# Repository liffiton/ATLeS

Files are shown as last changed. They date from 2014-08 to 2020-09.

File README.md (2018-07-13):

# ATLeS: Automated Tracking and Learning System

The goal of the ATLeS project is to create an inexpensive, open-source system for automated, high-throughput, realtime observation and conditioning experiments.  Zebrafish, *danio rerio*, are the target organism for the initial design.

ATLeS consists of one or more ATLeS boxes, each of which can run an automated experiment on a single organism at a time, and a separate server that provides a combined interface for managing and controlling all of the boxes and their experiments in one place.
Each box uses an inexpensive [Raspberry Pi](https://www.raspberrypi.org/) as its "brain," an infrared-sensitive camera as its "eyes," and inexpensive materials for the structure.
A central server can connect to boxes over a network (ethernet or wifi) to control and manage them via a web interface.
The server software is written in Python, and it runs under Linux, OS X, or Windows.

Please visit the main [ATLeS website](https://liffiton.github.io/ATLeS) or look in the ``docs`` folder for more details and documentation.

## Authors

ATLeS was created by [Mark Liffiton](https://www.iwu.edu/~mliffito/) and [Brad Sheese](https://sites.google.com/view/bradsheese-researchandteaching/) at [Illinois Wesleyan University](https://www.iwu.edu/).

## Open-Source Licenses

Each part of the ATLeS project is licensed under one of two open-source licenses, depending on what type of material it is.  See [``docs/licenses.md``](docs/licenses.md) for details.

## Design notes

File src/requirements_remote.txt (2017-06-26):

numpy
plumbum
rpyc!=3.4
zeroconf
wiringpi

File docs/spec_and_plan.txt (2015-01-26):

FishyCam
========

Overview
--------

The end goal is to make a Skinner box for zebrafish.  The box will sense the fish's position and give the fish visual feedback based on its position and the history thereof.

Tanks are roughly 30cm x 15cm x 5cm (just guesses).  Position sensing will be on the x-y (30cm and 15cm) axes.  Feedback will be presented on one side of the tank in the same plane.

Input
-----

Spec:
 * Resolution of 100 positions across (longest dimension) is fine.  10x10 would be workable.
 * Realtime sensing and feedback
 * Ideally: automatic detection of position and orientation of tank within frame.
   * For consistent, scaled coordinates across experiments

Ideas:
 * Camera
   + Simple hardware -- cheap, easy to put together
   - Issues with glare, filtering, etc.
 * IR Camera (rpi)
   + Simple hardware
   + IR sensitivity / filtering (http://publiclab.org/wiki/near-infrared-camera)
   * Note: RPI Python OpenCV V4L2 stuff: http://www.raspberrypi.org/forums/viewtopic.php?f=43&t=65026&start=25
 * Photosensors
   + More robust (?)
   - More complex -- have to custom build it

Automatic position/orientation detection:
 * Apply markers to 4 corners of tank (at bottom and at water line)
   * Differentiate by color?  (possibly easiest)
   * Use a unique pattern?
 * Detect prominent lines in tank and find 4 lines w/ most appropriate ratios/slopes to be the tank
   * http://stackoverflow.com/a/17265438

Output
------

Ideas:
 * Monitor
   + Most flexible -- any image/animation can be displayed
   + Simple hardware -- no construction required
   - Cost (potentially)
   - Issues with glare, filtering, given the camera is facing the display
 * Matrix of LEDs
   + Potentially easier to filter out
   + Inexpensive
   - Requires custom building
   - Low resolution

Plan
----

Webcam for sensing, monitor for feedback.

Software
--------

Interface needs:
  * Setup
    * ???
  * Monitor
    * Time experiment started, time running
    * View experiment parameters?
    * View current data?  (Form?)
    * Current video feed
      * Ideally live video, but a current still should be alright
  * Control
    * Stop experiment
  * Download
    * Data from previous experiment
    * Data from all past experiments
    * Data from selected experiment(s)
    * ?Form?

Interface options:
  * Web-based or GUI app
    * Web-based most accessible
    * GUI app runs where?  Via SSH?  Or physically at the machine itself?
  * Per-box or single centralized
    * Per-box is actually simpler to setup, maintain
    * Single centralized could be more usable

Data:
  * ???Form???
  * Centralized database?
    * Would be useful, but adds a lot of complexity

Feedback:
  * Animations?
    * If so, run in a separate thread
    * Thread 1: Track fish and make feedback decisions
    * Queue for messages, thr1->thr2
    * Thread 2: Animation, responding to messages in queue

API flow:
  frame = cv2.get...
  proc.proc(frame)
  tracker.update(proc.centroids)
  track.store(tracker.position)
  feedback.update(track)

General coding:
  * Use logging package, log any uncaught exceptions (crashes):
      http://blog.tplus1.com/blog/2012/08/05/python-log-uncaught-exceptions-with-sys-excepthook/
  * Animation:
     * Use pyprocessing for animation?
       http://code.google.com/p/pyprocessing/
     * Or use pyglet directly?
     * Pyprocessing will likely be easier for others to use for making new 'plugins'.
  * Use multiprocessing.{Process|Queue} for 'threading' and communication
  * Setup a 'plugin' architecture, with a directory for 'feedback' plugins and a directory for 'trigger' plugins?

**OR**
Build on pre-existing software:
  https://en.wikipedia.org/wiki/Comparison_of_behavioral_experiment_software
  * Python:
    * OpenSesame looks feature-rich
      * Uses PsychoPy or Expyriment for backends
    * PsychoPy also has a graphical experiment builder
    * Expyriment is code only, and it might not offer much we need...

Scripting options:
  * Let users create experiments in raw Python
  * Use a graphical editor like OpenSesame or PsychoPy (or one of those directly)
  * Blockly!  Can export to Python.  Can likely create custom blocks for various functions/variables of interest...!

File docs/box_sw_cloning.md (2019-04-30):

---
title: Box Software Cloning
---

# Box Software Cloning

These instructions are for developers who wish to clone an existing ATLeS box
Raspberry Pi installation to create a new base OS image for installing on new
boxes.

## Making a New Image

To save a disk image of a working/configured Raspberry Pi SD card:

[TODO: Could simplify to `dd` plus an automated script using loopback, https://github.com/Drewsif/PiShrink, and some of the steps below.]

1. Put card into card reader in a Linux machine.

2. (Optional) Use the `dist/prep_image.sh` script to remove unneeded files from
   the card before cloning.

3. Unmount the partitions if auto-mounted (Ubuntu auto-mounts them)

       $ sudo umount /dev/[device of auto-mounted partition[s]]

4. (Optional) Use `gparted` to shrink the root partition on the card to just
   the used space plus a small buffer.  (E.g., with 2.20GiB used, `resize2fs`
   wouldn't let me make it 2500MiB, but 3000MiB was okay.)

5. (Optional) Zero unused blocks in the root partition so the disk image can be
   compressed more.  Requires the `zerofree` utility.  If `/dev/sdc2` is the
   root partition:

       $ sudo zerofree -v /dev/sdc2

6. Determine the number of blocks now occupied.
   (Adapted from: [http://raspberrypi.stackexchange.com/a/8314](http://raspberrypi.stackexchange.com/a/8314))

       $ sudo fdisk -l /dev/[device of entire card (e.g., sdd)]
   
   Prints the partition table.

   Record 'End' of the final partition and the sector size.

7. Use `dd` to create the image using the size from the previous step.
    
       $ sudo dd bs=[sector size] count=[end of final partition + 1] if=/dev/[device of entire card] of=atles_rpi_`date +%Y%m%d`.img status=progress

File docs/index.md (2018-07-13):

---
title: Automated Tracking and Learning System
---

# ATLeS

The goal of the ATLeS project is to create an inexpensive, open-source system for automated, high-throughput, realtime observation and conditioning experiments.  Zebrafish, *danio rerio*, are the target organism for the initial design.

{:.center}
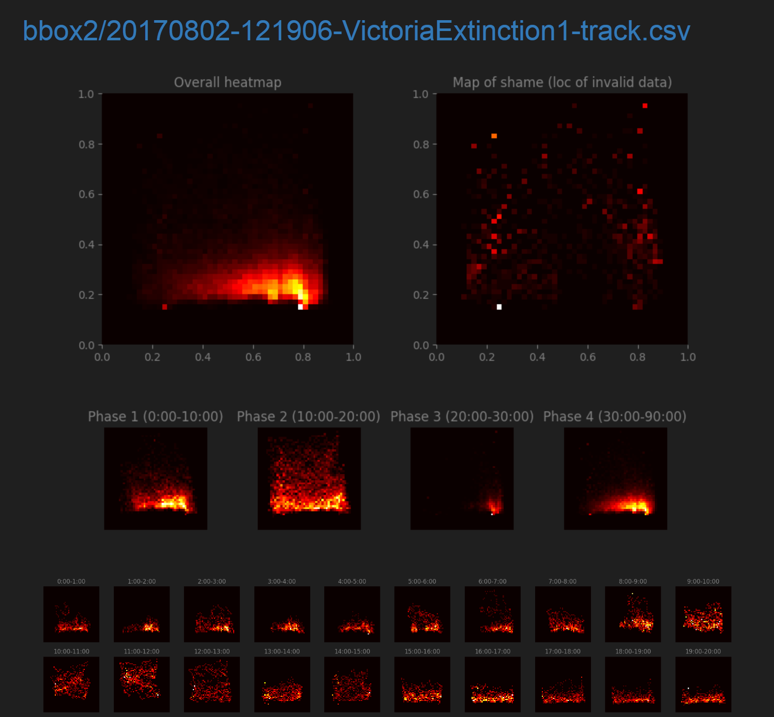
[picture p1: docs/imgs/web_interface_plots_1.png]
ATLeS Plots 1

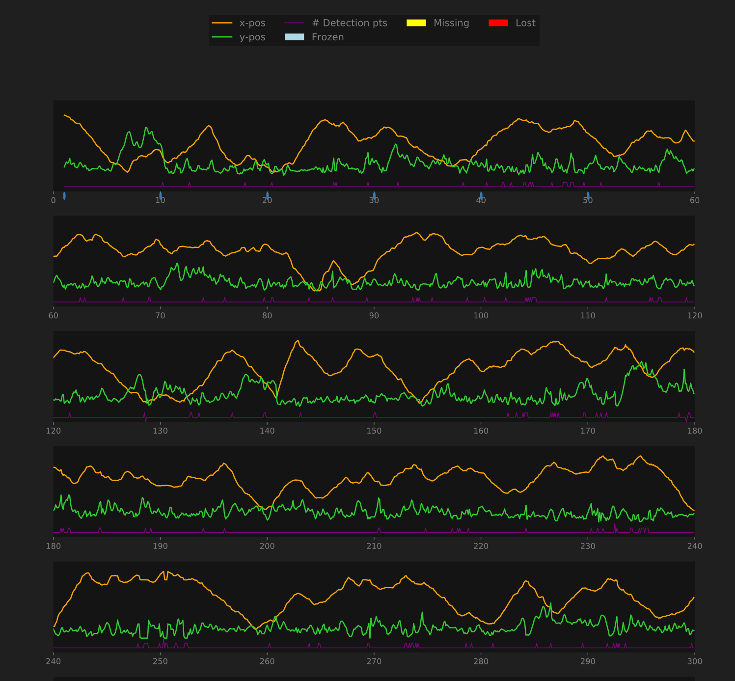
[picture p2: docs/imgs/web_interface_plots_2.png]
ATLeS Plots 2


ATLeS consists of one or more ATLeS boxes, each of which can run an automated experiment on a single organism at a time, and a separate server that provides a combined interface for managing and controlling all of the boxes and their experiments in one place.
Each box uses an inexpensive [Raspberry Pi](https://www.raspberrypi.org/) as its "brain," an infrared-sensitive camera as its "eyes," and inexpensive materials for the structure.
A central server can connect to boxes over a network (ethernet or wifi) to control and manage them via a web interface.
The server software is written in Python, and it runs under Linux, OS X, or Windows.

ATLeS was created by [Mark Liffiton](https://www.iwu.edu/~mliffito/) and [Brad Sheese](https://sites.google.com/view/bradsheese-researchandteaching/) at [Illinois Wesleyan University](https://www.iwu.edu/).

# Make Your Own

All source files, including code and complete designs for physical parts, are available in the [ATLeS Github repository](https://www.github.com/liffiton/ATLeS).

Building a single ATLeS box costs roughly $100 and requires some assembly and wiring.  The enclosure is designed to be laser cut from hardboard or similar flat, rigid materials.  Using the provided design files, you can either laser-cut the pieces yourself or order them from an online laser-cutting service.

{:.center}
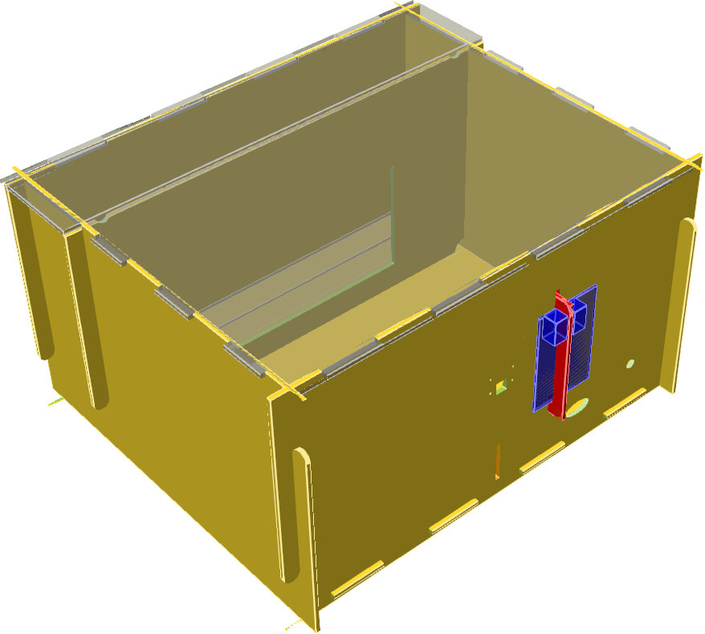
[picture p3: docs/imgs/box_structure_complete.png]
Complete ATLeS Enclosure


The following pages walk you through the assembly and software installation:

 * [Building an ATLeS Box Enclosure](building)
 * [System Integration & Setup](setup)

# Use It

After the boxes are assembled and the software is installed, run ``src/atles_web.py`` and point a browser to ``http://[hostname]:8080/``.  As you turn on boxes, they should become visible in the main web interface.

{:.center}
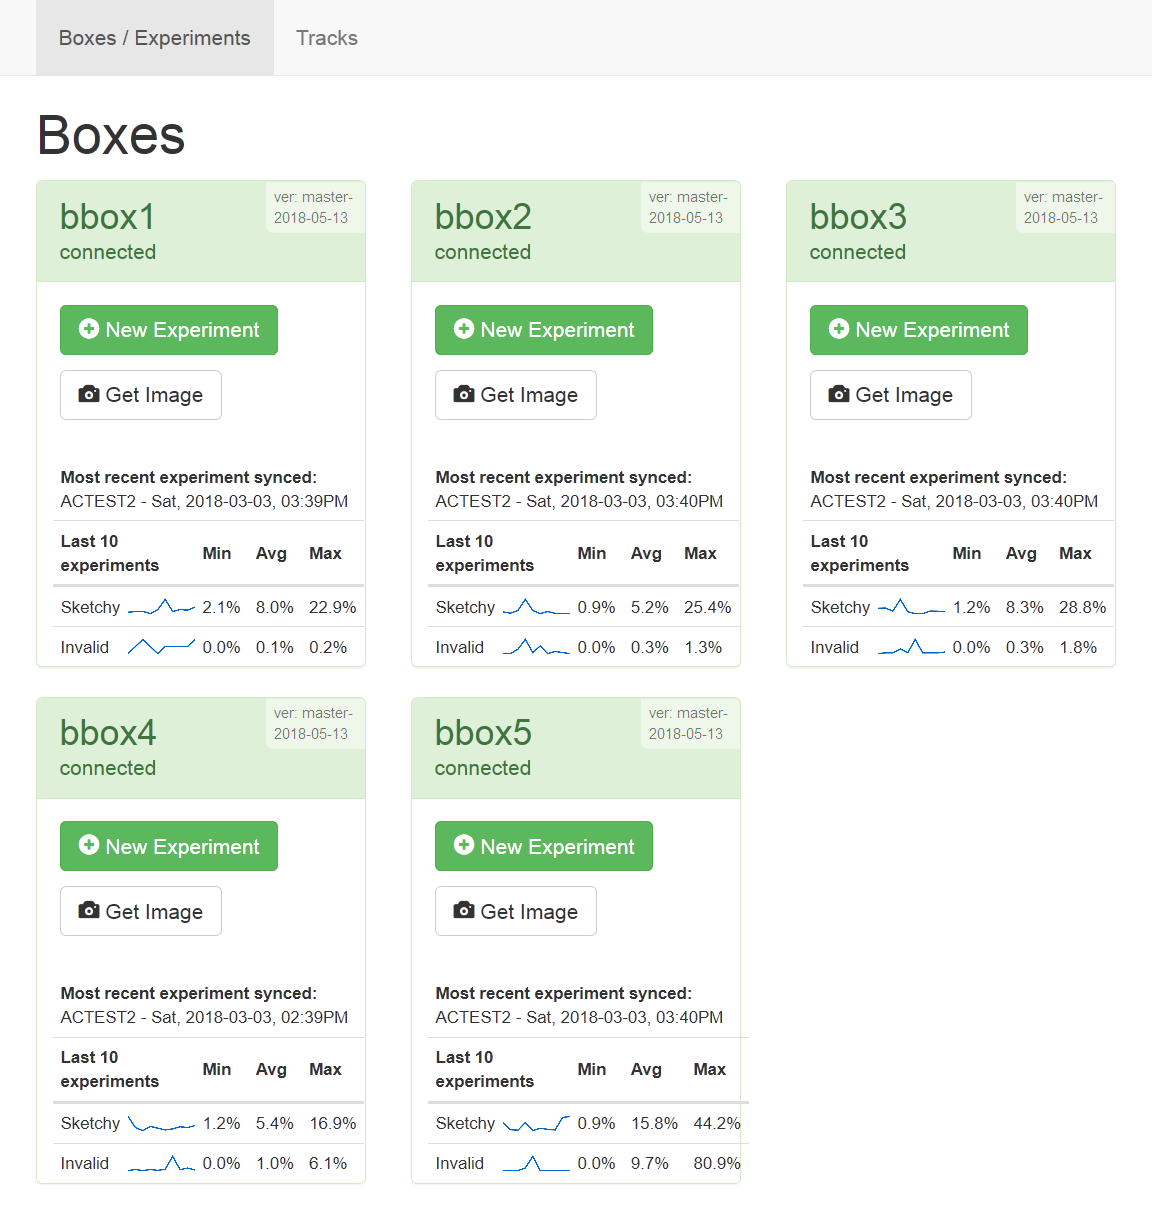
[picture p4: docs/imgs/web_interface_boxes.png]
Main ATLeS web interface


The web interface displays the status of every connected box, provides an interface for launching and monitoring experiments, and includes a full set of analysis and visualization tools for collected data.

The following page provides more details:

 * [Using ATLeS](usage)

# Adapt It

Because the entire system is open-source, from the code to the physical design, you can modify and adapt the system to suit your needs.  Modify the enclosure to accommodate a different style of tank.  Tweak the software to perform a different analysis.  Or just take a component out to use in your own system.  See [Licenses](licenses) for details.

The following pages provide information for anyone interested in modifying or working on the software:

 * [(Manual) box software installation](box_sw_manual_install)
 * [Box software image cloning](box_sw_cloning)
 * [Box software usage notes](box_sw_notes)

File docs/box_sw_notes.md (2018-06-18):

---
title: Box Software Usage Notes
---

# Notes on Running `atles_box.py`

## Framerate

The capture framerate is sensitive to many things.

First, displaying the captured frames using highgui takes a huge amount of CPU time, making it infeasible (i.e., maxing out CPU) above 10fps.  Without displaying the images, however, CPU usage doesn't hit 100% until about 50fps.

Secondly, the capture size obviously makes a difference.  There is currently some bug in the interaction between OpenCV and V4L that makes it impossible to change the capture size after the stream is opened in OpenCV (at its default 640x480 size).  See [opencv_notes](opencv_notes) for directions for how to modify and compile OpenCV to fix this bug.  The fix allows us to set the video capture size smaller for better performance.  160x120 seems nice and fast, and we have lots of flexibility now.

Also, it is important to note that terminal output, displayed on the rpi's X server, uses a large amount of the CPU as well.  Simply switching to a different tab while FPS output is enabled in camtest.py drops the CPU usage significantly.  Keep this in mind particularly during testing, where debugging output may significantly harm performance.

## Exposure and white balance

Auto white balance can be disabled with:

    $ v4l2-ctl --set-ctrl=white_balance_auto_preset=1
    $ v4l2-ctl --set-ctrl=white_balance_auto_preset=0

It does seem to need to be set to 1 then back to 0 to work, at least sometimes.  Without that, AWB is somehow enabled between(?) runs, and just setting the preset to 0 at the start of the next does not work.  The set to 1 then back does work, it appears.

Exposure can be adjusted with:

    $ v4l2-ctl --set-ctrl=auto_exposure=1
    $ v4l2-ctl --set-ctrl=exposure_time_absolute=10000
    $ v4l2-ctl -p 1

"auto_exposure=1" disables auto exposure (don't ask me...).
"exposure_time_absolute" is given in multiples of 0.1ms.  It needs to be adjusted along with the frame rate (-p) so that they match.  A higher frame rate will clip the exposure to make that frame rate possible.

## Display

In X, pygame will make a fullscreen view, but it won't (as far as I've found so far) scale the image.  So if I request 640x480, I get a 640x480 surface in the middle of my monitor.

Running from the terminal, however, does work.  I don't know what interface SDL is using, exactly, but it seems alright.  It seems to only work *once*, though.  Running the program a second time results in a blank screen.  I may be using Pygame incorrectly...

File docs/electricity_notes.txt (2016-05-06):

May 6, 2016

Measuring resistance through H2O between two pieces of Al foil:  multimeter says >2MOhm.

Current:
  * Measured by DMM with voltage set on power supply
  * With Al foil on **inside** of plastic baffles, right at baffles:
    * 32V -> 75mA
    * 20V -> 47mA
    * 15V -> 35mA
    * 10V -> 22mA
    * 5V  -> 10mA
    * 2V  ->  3mA
  * With Al foil on **outside** of plastic baffles (only conductance via thin gaps at edges):
    * 20v -> 16mA
  * Baffles **block a lot**

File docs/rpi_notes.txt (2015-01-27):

FishyCam on the Raspberry Pi
============================

Package dependencies
--------------------

python-smbus

**TODO (others?)**

Runtime dependencies
--------------------

In order to use the camera via v4l, one must first load a module:

  sudo modprobe bcm2835-v4l2

Then, OpenCV's v4l2 support works reasonably well (though see Framerate below).

Using the i2c interface also requires a module:

  sudo modprobe i2c-bcm2708
  sudo modprobe i2c-dev

Alternatively, you can add the modules to /etc/modules, one per line:

   bcm2835-v4l2
   i2c-bcm2708
   i2c-dev

Framerate
---------

The capture framerate is sensitive to many things.

First, displaying the captured frames using highgui takes a huge amount of CPU time, making it infeasible (i.e., maxing out CPU) above 10fps.  Without displaying the images, however, CPU usage doesn't hit 100% until about 50fps.

Secondly, the capture size obviously makes a difference.  However, there is currently some bug in the interaction between OpenCV and V4L that makes it impossible to change the capture size after the stream is opened in OpenCV (at its default 640x480 size).  However, a user on the rpi forums has posted a fix to OpenCV:
  http://www.raspberrypi.org/forums/viewtopic.php?f=43&t=62364&start=322

It requires modifying and recompiling OpenCV.  I have adopted his/her modifications, allowing me to set the video capture size smaller for better performance.  160x120 seems nice and fast, but we have lots of flexibility now.

Secondly, then, it is important to note that terminal output, displayed on the rpi's X server, uses a large amount of the CPU as well.  Simply switching to a different tab while FPS output is enabled in camtest.py drops the CPU usage significantly.  Keep this in mind particularly during testing, where debugging output may significantly harm performance.

Exposure and white balance
--------------------------

Auto white balance can be disabled with:
 v4l2-ctl --set-ctrl=white_balance_auto_preset=1
 v4l2-ctl --set-ctrl=white_balance_auto_preset=0

It does seem to need to be set to 1 then back to 0 to work, at least sometimes.  Without that, AWB is somehow enabled between(?) runs, and just setting the preset to 0 at the start of the next does not work.  The set to 1 then back does work, it appears.

Exposure can be adjusted with:
 v4l2-ctl --set-ctrl=auto_exposure=1
 v4l2-ctl --set-ctrl=exposure_time_absolute=10000
 v4l2-ctl -p 1

"auto_exposure=1" disables auto exposure (don't ask me...).
"exposure_time_absolute" is given in multiples of 0.1ms.  It needs to be adjusted along with the frame rate (-p) so that they match.  A higher frame rate will clip the exposure to make that frame rate possible.

Display
-------

In X, pygame will make a fullscreen view, but it won't (as far as I've found so far) scale the image.  So if I request 640x480, I get a 640x480 surface in the middle of my monitor.

Running from the terminal, however, does work.  I don't know what interface SDL is using, exactly, but it seems alright.  It seems to only work *once*, though.  Running the program a second time results in a blank screen.  I may be using Pygame incorrectly...

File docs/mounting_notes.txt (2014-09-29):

Mounting the Raspberry Pi and Camera
====================================

Requirements
------------

  * Camera must be held in correct orientation (i.e., right-side-up).
  * Camera must be facing fish tank.
  * Camera should be as close to a set distance from and orientation w.r.t. the fishtank as possible.
  * Raspberry Pi must be within flex-cable-range of camera.
  * SD card, USB, HDMI, and ethernet must all be accessible on RPi.
  * Monitor should be mounted in set position w.r.t. fishtank.
  * All should be splash-proof (for whatever direction splashes might come from).

Ideas
-----

Monitor:
  * VESA mount would accomodate most regular monitors, but:
    * Most regular monitors are larger than needed
    * There are two(?) VESA standards
    * Even w/in same monitor size, VESA mounts are likely not all in same position on monitor
  * Specific smaller monitor
    * E.g.: https://www.adafruit.com/products/1287 ($150ish)
    * Requires mounting monitor and control board

Construction:
  * Clear acrylic
    * Camera, Pi, monitor(?) mounted w/ simple bolts through mounting holes
      * Consider nylon screws/nuts, if you can find them.
      * For RPi, M2.5 or 4-40 screws should work fine.  4-40 plentiful at HD.
      * For camera, M2 screws work, and imperial size 2 (e.g. 2-56) might *just* fit...  Imperial size 1 is better, but...  not easy to find.
    * Holes in acrylic drilled *or* laser-cut
    * Simple, splash-proof from direction of tank
    * ? How to hold two pieces of acrylic (w/ some load) vertically in correct position?
      * Threaded rod?  Seems good.
      * Acrylic side pieces as well?  Then could be 100% laser-cut.
    * ? How to position fishtank?
      * Bottom piece of acrylic w/ laser-cut slots for tank "feet"?
      * Cut piece for holding outline of tank in place?

Existing enclosure designs
==========================
  * Enclosure for camera alone
    * https://github.com/luisibanez/ShapesFor3DPrinting/tree/master/OpenSCAD
      * Shown on https://www.thingiverse.com/thing:214466
  * Enclosure for Pi alone
    * http://www.thingiverse.com/thing:16104/
  * Full enclosure for Pi and Camera
    * http://www.thingiverse.com/thing:177816
    * http://www.thingiverse.com/thing:142608
    * http://www.thingiverse.com/thing:89745
    * Note remixes of above, as well
    * Cleaner, but not entirely needed...
    * But definitely better protection for electronics...

Questions
---------
  * Lighting?  Need sufficient for camera.  Does it need to be constant / standard for any experiments?

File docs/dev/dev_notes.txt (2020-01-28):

"Dev" RPi 3 B+: 10.2.6.36  [in Mark's office]
fishhead: 10.2.53.25

To run main web interface:
  sudo python src/atles_web.py --daemon

Fish tank measurements:
 - Height w/ feet:   16.0cm
 - Height w/o feet:  15.4cm
 - Width:             7.0cm
 - Length w/ lid:    34.8cm
 - Length w/o lid:   33.3cm
 - Diagonal (approx. screen size needed): 14.4" (36.7cm)

Electricity
-----------
May 6, 2016

Measuring resistance through H2O between two pieces of Al foil:  multimeter says >2MOhm.

Current:
  * Measured by DMM with voltage set on power supply
  * With Al foil on **inside** of plastic baffles, right at baffles:
    * 32V -> 75mA
    * 20V -> 47mA
    * 15V -> 35mA
    * 10V -> 22mA
    * 5V  -> 10mA
    * 2V  ->  3mA
  * With Al foil on **outside** of plastic baffles (only conductance via thin gaps at edges):
    * 20v -> 16mA
  * Baffles **block a lot**

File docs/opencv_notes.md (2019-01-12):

These notes are out of date and preserved just in case.  Follow the instructions in [box_sw_manual_install](box_sw_manual_install) instead.

Installing an Updated OpenCV on the Raspberry Pi
===============================================

The following instructions assume an updated Raspbian system.

Based on [OpenCV Linux Install][].

[To build/install on Cygwin, see [OpenCV Cygwin Install][].]

[OpenCV Linux Install]: http://docs.opencv.org/doc/tutorials/introduction/linux_install/linux_install.html
[OpenCV Cygwin Install]: http://hvrl.ics.keio.ac.jp/kimura/opencv/

Build dependencies
------------------

Packages that need to be installed in addition to the defaults.  [There may be
something missing here that isn't included in the default Raspbian install, but
this is what I had to add to my current setup.]

```
cmake
libgtk2.0-dev
python3-dev
libavcodec-dev
libavformat-dev
libswscale-dev
libpng-dev
libjasper-dev
libtiff-dev
```

To install these:

    $ sudo apt-get install cmake libgtk2.0-dev python3-dev libavcodec-dev libavformat-dev libswscale-dev libpng-dev libjasper-dev libtiff-dev

Download OpenCV
---------------

ATLeS currently works and has been tested with OpenCV 3.2.0.  You can download
this release from [OpenCV's Releases page](http://opencv.org/releases.html).
ATLeS will likely work with other versions, but compatibility is not guaranteed.

Build instructions
------------------

In the opencv-3.2.0 directory, run:

```sh
$ mkdir release
$ cd release
$ cmake -D CMAKE_BUILD_TYPE=RELEASE -D CMAKE_INSTALL_PREFIX=/usr/local -D BUILD_EXAMPLES=off -D BUILD_TESTS=off -D BUILD_PERF_TESTS=off ..
```

In the output of cmake, verify that "OpenCV modules">"To be built" lists
python, "GUI" has "YES" for GTK+, and the "Python" section lists correct paths
to binaries/libraries.  Tests, examples, and performance tests are not built to
save space.  It takes far too much space with those enabled (I ran out of space
with 1.1GB free to start).

    $ make

This step, building OpenCV with the above configuration, takes about 4 hours on
the RPi B+.

    $ sudo make install

The easiest way to check the installation now is to launch the python
interpreter and type `import cv2`.  If it does not report an error when
importing the module, the installation is probably complete.

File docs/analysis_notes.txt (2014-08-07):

From Brad's hand-written notes (Jul 2014)

Cachet et al. 2010
------------------

 * # of entries to top
 * Entries top/bottom ratio
 * Time spent in top (s)
 * Time spent top/bottom ratio
 * Average entry duration (time spent in top divided by the number of entries to top)
 * Distance traveled in top (m)
 * Distance traveled top/bottom ratio
 * Latency to enter the top (s)
 * # of erratic movements
 * Freezing bouts (frequency)
 * Freezing duration (s)
 * Distance traveled (m)
 * Velocity (m/s)
   [note for last two: 'claim these represent hyperactivity']

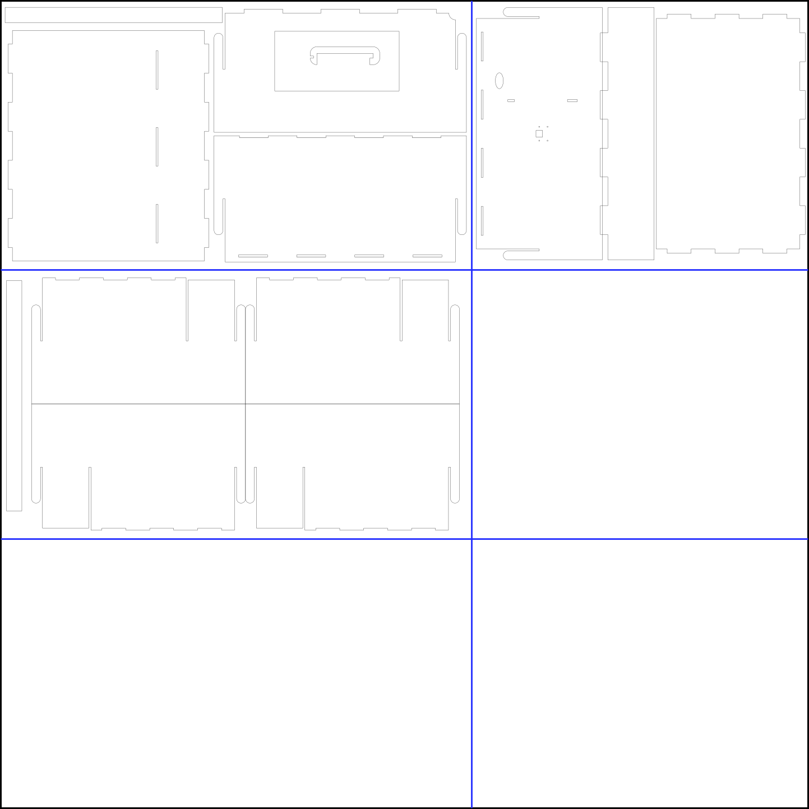
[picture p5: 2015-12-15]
designs/box/paneling.png

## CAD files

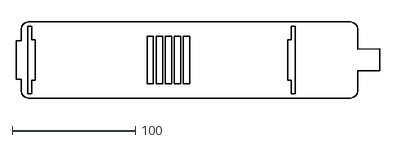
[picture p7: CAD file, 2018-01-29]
designs/dist/tank_lid_for_shock.dxf
294.6 x 61.7

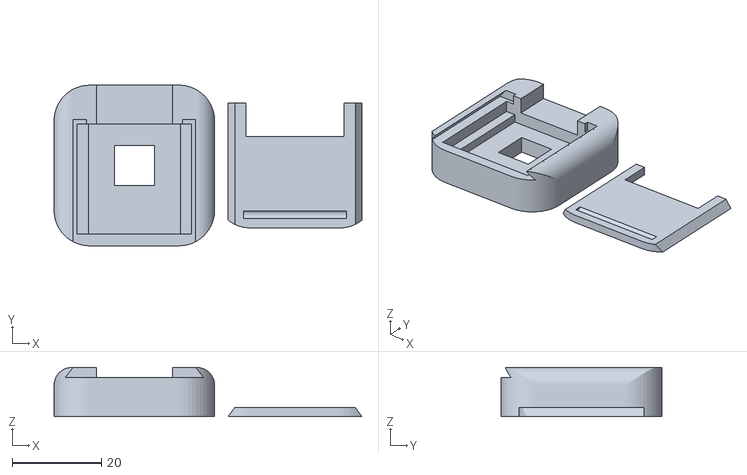
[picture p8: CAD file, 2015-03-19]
designs/piCameraEnclosure.stl
69.0 x 36.0 x 11.0

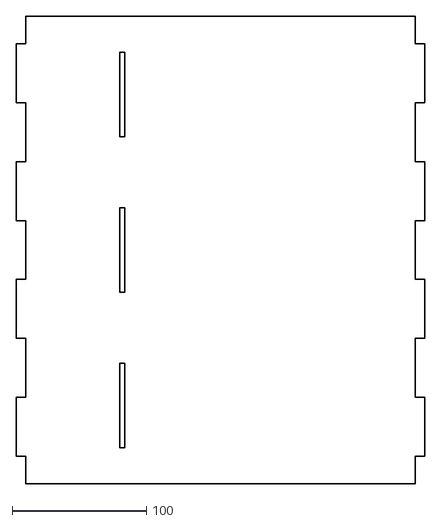
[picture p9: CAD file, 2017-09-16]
designs/dist/bottom.dxf
304.5 x 348.0

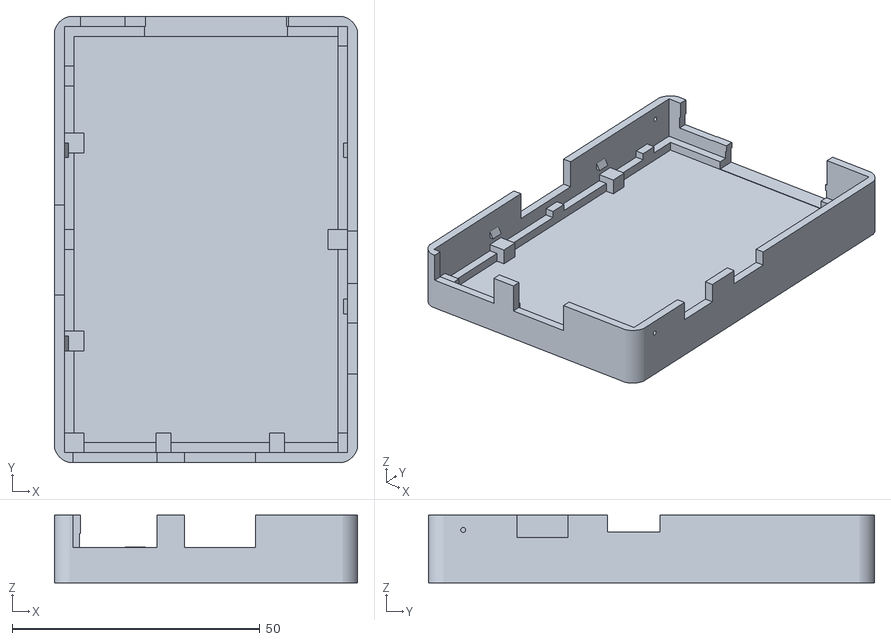
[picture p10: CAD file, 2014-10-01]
designs/RaspberryPi_v15_bottom.stl
61.2 x 90.0 x 13.7

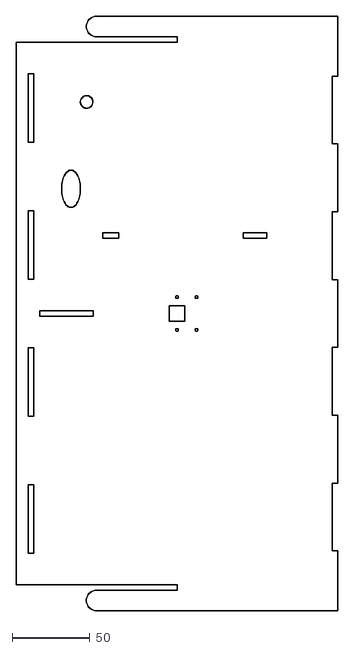
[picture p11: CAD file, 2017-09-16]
designs/dist/end2.dxf
206.0 x 381.5

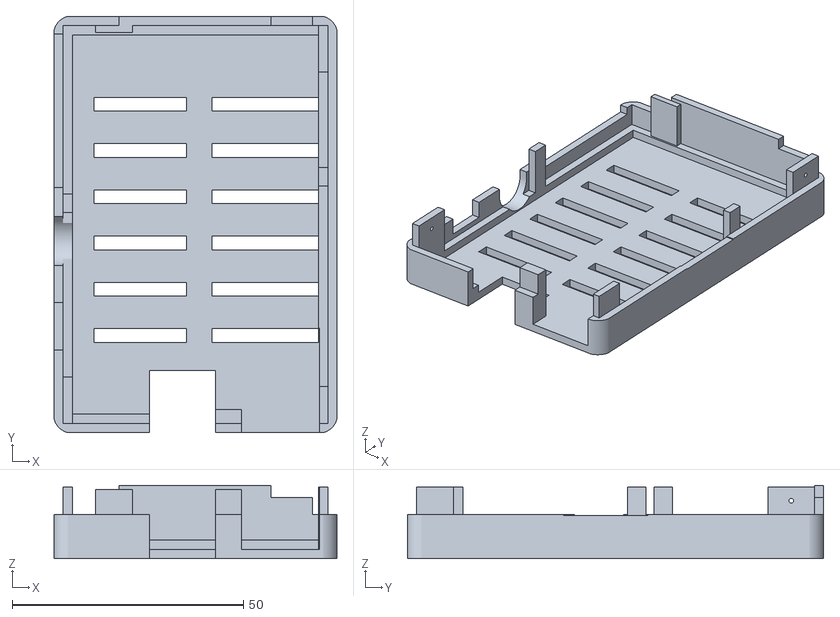
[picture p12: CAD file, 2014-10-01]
designs/RaspberryPi_v15_top.stl
61.2 x 90.0 x 15.8

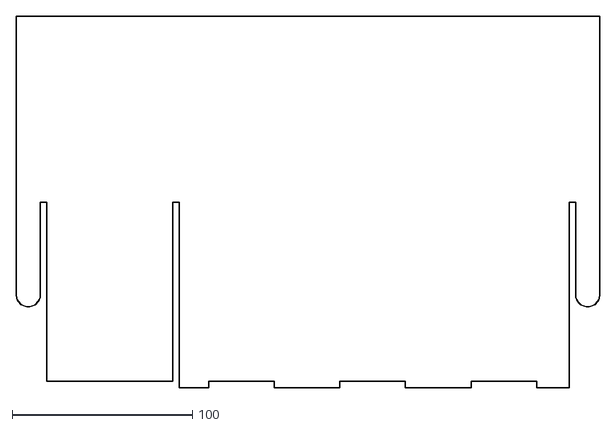
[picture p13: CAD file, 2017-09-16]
designs/dist/side1.dxf
323.5 x 206.0

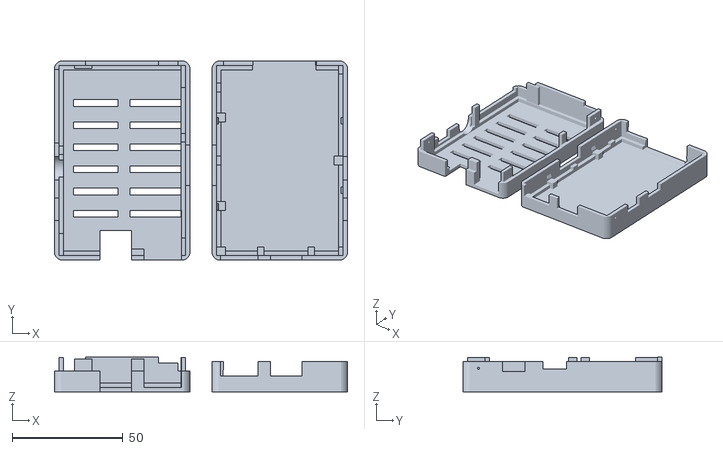
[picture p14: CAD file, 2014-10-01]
designs/RaspberryPi_v15.stl
132.4 x 90.0 x 15.8

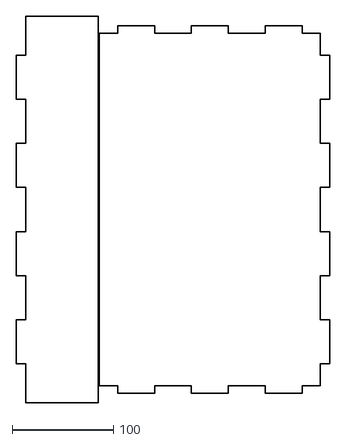
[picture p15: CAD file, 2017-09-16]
designs/dist/top.dxf
309.0 x 381.5

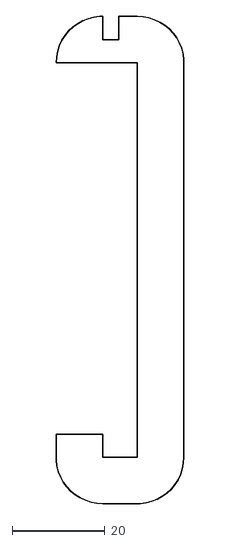
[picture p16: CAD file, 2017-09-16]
designs/dist/rpi_support.dxf
27.5 x 105.0

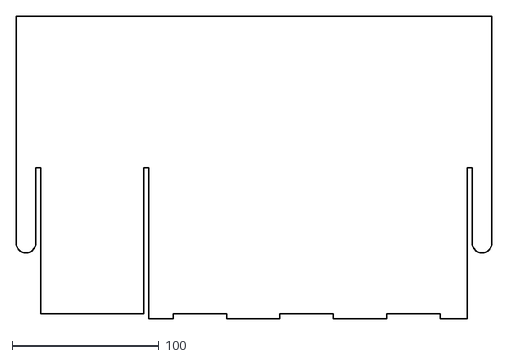
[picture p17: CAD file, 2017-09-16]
designs/dist/side2.dxf
323.5 x 206.0

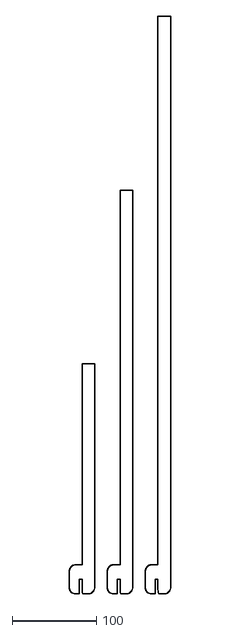
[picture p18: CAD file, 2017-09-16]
designs/dist/rear_support.dxf
120.0 x 684.5

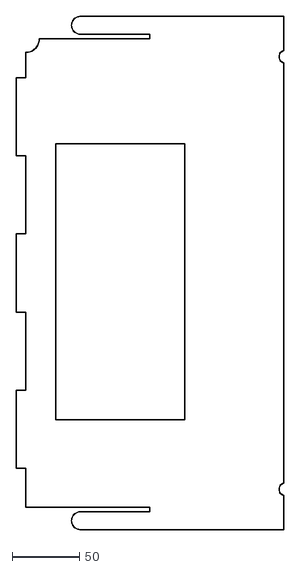
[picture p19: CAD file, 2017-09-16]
designs/dist/mask.dxf
198.5 x 381.5

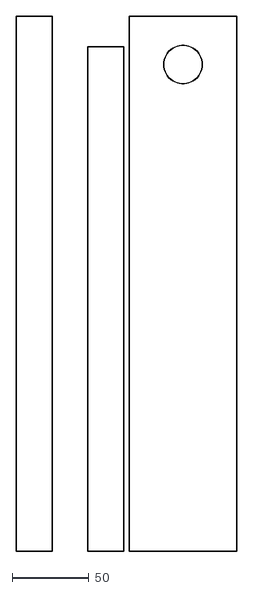
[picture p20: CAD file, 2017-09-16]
designs/dist/tank_support.dxf
143.5 x 348.0

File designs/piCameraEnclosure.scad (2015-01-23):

// Adapted from: https://github.com/luisibanez/ShapesFor3DPrinting/tree/master/OpenSCA

// For case
width  = 36;  // x
length = 36;  // y
height = 11;  // z

// For camera cover
flex_adapter_width = 22;   // measures 21mm, but w/ a nominal 22mm opening it was still too tight.
cover_width = 27;
cover_height = 2;

// For rounded corners
radius1 = 8;
radius2 = 4;

piCameraAdapter();
// Comment out translate to see
// back cover in place.
translate([width,4,-(height-cover_height)])
    piCameraBackCover();


/////////////////////////////////////////////////////////////////////////////////////
// Modules
//

module piCameraBackCoverBevel(length, clearance) {
    c = clearance;
    hh = cover_height / 2;
    hw = ( cover_width / 2 ) + c;
    he = hw + 1.5 + c;
    l = length / 2;
    polyhedron(
        points = [
            [ hw, -l-c, -hh-c ],
            [ hw,  l+c, -hh-c ], 
            [ hw,  l+c, hh ], 
            [ hw, -l-c, hh ],
            [ he, -l-c, -hh-c ],
            [ he,  l+c, -hh-c ] 
            ], 
        faces = [
            [ 5, 1, 0, 4],
            [ 4, 0, 3 ],
            [ 2, 1, 5 ],
            [ 5, 4, 3, 2],
            [ 0, 1, 2, 3],
        ]
    );
}

module piCameraBackCover(for_subtraction=false) {
    indent = ! for_subtraction;
    clearance = for_subtraction ? 0.25 : 0;
    c = 2*clearance;
    cov_l = length-8;
    difference() {
        translate([0,-5,height-cover_height/2])
        difference() {
            translate([0,1,0])
            union() {
                cube(size=[cover_width+c,cov_l+c,cover_height+c],center=true);
                piCameraBackCoverBevel(cov_l, clearance);
                mirror([1,0,0])
                    piCameraBackCoverBevel(cov_l, clearance);
            }
            translate([0,15,0])
                cube(size=[flex_adapter_width-c,15,100],center=true);
            if (indent)
                translate([0,8-length/2,cover_height/2+0.5])
                rotate([0,90,0])
                    cylinder(r=1, h=cover_width-4, center=true, $fn=20);
        }
        if (! for_subtraction) {
            cornerRounding();
        }
    }
}

module cableOpening() {
    w = 17;
    d = 12;
    h = 100;
    translate([-w/2,2+d/2,height-4+0.1])
        cube(size=[w,d,h]);
}

module lensOpening() {
    clearance = 0.5;
    c = 2 * clearance;
    w = 8+c;
    d = 8+c;
    h = 100;
    translate([-w/2,-d/2,-1])
        cube(size=[w,d,h]);
}

module boardOpening() {
    clearance = 0.3;
    c = 2 * clearance;
    w = 25+c;
    d = 24+c;
    h = 100;
    translate([-w/2,-d/2 - 3, height-5])
        cube(size=[w,d,h]);
}

module chipOpening() {
    clearance = 0.3;
    c = 2 * clearance;
    w = 20+c;
    d = 24+c;
    h = 100;
    translate([-w/2,-d/2 - 3, height-7])
        cube(size=[w,d,h]);
}

module cameraFrame() {
    translate([0,0,height/2])
        cube(size=[width,length,height], center=true);
}

module roundedCorner(r) {
    translate([-r, -r, 0])
    difference() {
        translate([0,0,-50])
            cube(size=[r+0.1,r+0.1,100]);
        cylinder(h=100, r=r, $fn=50, center=true);
    }
}

module cornerRounding() {
    // vertical corners
    translate([width/2,length/2,0])
        roundedCorner(radius1);
    translate([-width/2,length/2,0])
    rotate([0,0,90])
        roundedCorner(radius1);
    translate([-width/2,-length/2,0])
    rotate([0,0,180])
        roundedCorner(radius1);
    translate([width/2,-length/2,0])
    rotate([0,0,-90])
        roundedCorner(radius1);

    // top corners
    translate([-width/2,0,height])
    rotate([0,-90,0])
    rotate([90,0,0])
        roundedCorner(radius2);
    translate([width/2,0,height])
    rotate([90,0,0])
        roundedCorner(radius2);
}

module piCameraAdapter() {
    difference() {
        cameraFrame();
        boardOpening();
        chipOpening();
        cableOpening();
        lensOpening();
        cornerRounding();
        piCameraBackCover(for_subtraction=true);
    }
}

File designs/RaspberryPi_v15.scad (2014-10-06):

// Raspberry Pi Case
// Hans Harder 2012
//
// Warning: this is based on the Beta board dimensions...
//          so production models can be slightly different
//          for instance SD card holder height and USB socket dimensions
//
// Since all connectors stick out, case is split on HDMI height
// so the power and sdcard holder goes in first and then the pcb drops into place.
//
// v2: Adapted version after some suggestions from David...
//     removed feet, made both surface flat
// v3: Added fliptop option and smooth the corners of the box
// v4: Different levels of case split (make it 3d printable, thx David)
//     Looks strange but it fits...
//     Added frame mode (so no bottom and top deck)
//     Moved screw locations due to split and added some support structures
//     Unsure about 2nd screw location in combination with GPIO pins
// v5  relocated a lot of code in modules
//     SDslot location was not calculated correctly
// v6  Added pcb drawing
//     Added colors
//     Cut out better so there is no debris around
//     DRAwvars and options seperated, so it is easier to do 1 part
//     Make a low as possible case, let USB stick out
// v7  PCB options
//     Low level case optimisations
//     SD card location alterations
// v8  adapted pcb dimensions, board is really 56mm width
//     adapted support studs, moved some due to component location
//     components locations adapted
// v9  Added logo in seperate dxf file
//     Option added to put logo in middle or using whole deck
//     beautified code, kr style
// v10 Added logosunken and bottomsupport structures
//     Bottom supports are located where no components are located
//       so the pcb is not only supported from the sides
//     Well got my case, so based on what I see I changed:
//     case split level changed, should be better when printed on a reprap
//     Removed screwholes (far to small) for fastening top and added some more studs
//     Made frontstud a little thicker
// v11 Different splitlevel (more simple) on back
//     keep a little margin on back split, so that top and bottom always fit
//     added openlogo option
// v12 Different component locations/sizes
//     keep a little margin on component holes
//     pcbsize to 57.0 x 86.0   (actual it is 56.17 x 85.0)
//     made casestuds wider and added 2 minor holes for self tapping screws
// v13 skip this one.... :)
// v14 Production board measurements...
//	   small differences, sometimes components are soldered differently
//     keep more space
//     should fit like a glove...
// v15 moved the rca and snd a bit to get them more centered
//     Thanks to lincomatic at Thingiverse
//     Added option for GPIO side hole in bottom or top
//     Added showing GPIO pins with component drawing
//
// All parts are draw as default just disable the ones you don't want
DRAWfull        = 0;
DRAWtop         = 1;
DRAWbottom      = 1;
DRAWpcb         = 0;

GPIOHOLE        = 2;        // GPIO opening in :  1=bottom   2=top
GPIOsize        = 2;        // define height of gpiohole

// select how the case should look like
topframe    = false;        // if false, underneath values determines how
topholes    = true;
ledholes    = true;
// ---- holes sizes
holeofs=6;
holesiz=3;
holestep=8;
noholes=7;
holelen=30;
topmiddle   = false;

bottomframe = false;        // if false, underneath values determines how
bottomholes = false;
bottomscrew = false;
bottomsupport = false;         // Added extra support locations for pcb
bottomclick   = true;
bottompcb    = false;		    // just a pcb holder without a top

box_thickness = 2.0;            // minimum = 1.0
inside_h      = 12.5;           // 12.1 = lowprofile    16.5 is full height
pcb_h         = 5.6;            // height needed for SD holder and solder points of pcb
//pcb_h         = box_thickness+3.5;    // height needed for SD holder and solder points of pcb
// 4.1 = no deck, box_thickness+3.5 is with deck

// just some colors to see the difference
CASEcolor="Maroon";
CONNcolor="Silver";

// Define Raspberry Pi pcb dimensions in mm
inside_l = 86.0;                //85.00 is largest length reported, so a bit room on each side
inside_w = 57.2;                //56.17 is largest width  reported, so a bit room on each side
pcb_thickness = 1.7;

// Coordinates based on RJ45 corner = 0,0,0
// pcb connectors and locations. Based on Beta Board measurements of Gert and a real RPi

// Connectors
Crj45_x=2.0;			 //2.0
Crj45_y=-1;
Crj45_w=16.4;			// 15.4
Crj45_d=21.5;           //21.8
Crj45_h=13.8;

Cusb_x=24.5;            // 23.9
Cusb_y=-7.7;
Cusb_w=13.9;            // 13.3
Cusb_d=19.0;			// 17.2
Cusb_h=16.0;

Cpwr_x=3.25;				// 3.5 3.6
Cpwr_y=80.9;
Cpwr_w=8.8;				// 7.8 7.6
Cpwr_d=5.6;
Cpwr_h=2.6;

Csd_x=16.7;
Csd_y=inside_l-24.0;            // 30 mm is the length of a  sdcard
Csd_w=27.8;
Csd_d=29.0;
Csd_h=3.4;                  // under pcb

Chdmi_x=-1.2;
Chdmi_y=32.0;               // 32.4  if 15.1
Chdmi_w=11.4;
Chdmi_d=17.8;				  // 15.7 15.3
Chdmi_h=6.4;

Csnd_x=inside_w - 11.4;
Csnd_y=16.0;
Csnd_w=11.4;
Csnd_d=10.0;
Csnd_h=10.5;
Csnd_r=6.7;
Csnd_z=3.0;
Csnd_l=3.4;

Crca_x=inside_w - 10.0 - 2.1;
Crca_y=34.2;                // 34.6 was 35.2
Crca_w=10.0;
Crca_d=10.4;                 // 9.8
Crca_h=13.0;
Crca_r=8.6;
Crca_z=4;
Crca_l=10;                  // wild guess



pcb_c = pcb_h + pcb_thickness;            // component height
casesplit = pcb_c + Chdmi_h;              // split case at top of hdmi connector
echo("casesplit=",casesplit);
echo("case dimensions: w=",box_w," l=",box_l," h=",box_h);

// side stud sizes for supporting pcb
stud_w = 2;
stud_l = 4;

// calculate box size
box_l  = inside_l + (box_thickness * 2);
box_w  = inside_w + (box_thickness * 2);
box_h  = pcb_c + (pcb_thickness * 2) + inside_h;
box_w1 = box_thickness;
box_w2 = box_w - box_thickness;
box_l1 = box_thickness;
box_l2 = box_l - box_thickness;
box_wc = box_w / 2;                 // center width
box_lc = box_l / 2;                 // center length
box_t2 = box_thickness / 2.0;           // half box_thickness
middle = true;
// rounded corners
corner_radius = box_thickness*2;



// count no of items to draw
DRAWtotal = DRAWfull + DRAWtop + DRAWbottom;

// ====================================================== DRAW items
// if one  draw it centered
if (DRAWtotal == 1) {
    translate(v = [ -box_w/2, -box_l / 2, 0]) {
        if (DRAWfull ) {
           draw_case(0,1);
           translate(v=[0,0,0.2]) draw_case(1,0);
        }
        if (DRAWtop   ) {
            rotate(a=[0,180,0]) translate(v=[-box_w,0,-box_h]) draw_case(0,1);
        }
        if (DRAWbottom) draw_case(1,0);
    }
} else {
// draw each one on there one location
    if (DRAWfull)   {
        translate(v = [ box_w+20, -box_l / 2, 0]) {
            draw_case(1,0);
            translate(v=[0,0,0.2]) draw_case(0,1);
        }
    }
    if (DRAWbottom) {
        translate(v = [ 5, 5, 0]) draw_case(1,0);
    }
    if (DRAWtop)    {
        translate(v = [ - 5,  5, box_h])  rotate(a=[0,180,0]) draw_case(0,1);
    }
}

// ======================================================= END of draw
// Module sections

module make_deckholes(no,w,d,step) {
for ( i = [0 : 1 : no - 1] ) {
        translate(v=[w/2,(i*step)+(step/2),box_thickness/2]) cube([w,d, box_thickness+18], center=true);
    }
}
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

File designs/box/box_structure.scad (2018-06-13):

// fishbox.scad
//  - Enclosure design for zebrafish Skinner box
//  
//  Author: Mark Liffiton
//  Date: Oct, 2014 - Nov, 2015
//
//  Units are mm

// Set thickness to account for thickness of material
// PLUS needed clearance for cuts into which material should fit.

// 0.100" Acrylic:
acrylic_thickness = 2.4;
    // 2.4mm = 0.094" (looks good based on cut test piece for acrylic slotting into itself)

// 1/8" Hardboard:
hardboard_thickness = 3.5;
    // 2.8mm = 0.110"
    //   * looked good based on cut test piece for hardboard slotting into hardboard
    //   * 2015-03-06: Hanging supports didn't fit into cutouts (or did only with lots of force)
    // 3.1mm for some breathing room
    //   * 2016-02-26: Still tighter than is ideal for sliding parts together.
    // 3.3mm for just a smidge more...
    //   * 2016-06-17: 3.3 is *still* too tight in a few connections!
    //                 Most are fine, but we need to handle the variability
    //                 in material thickness, so...
    // 3.5mm.  (Final?)

// Assign materials: window/back wall and everything else
//window_thickness = acrylic_thickness;
window_thickness = hardboard_thickness;
thickness = hardboard_thickness;

// Interior box dimensions
// The variables are used below to control placement of **centerpoints** centerpoints of walls,
// so material thickness is added to account for that.
width = 290 + thickness;    // x = 29cm wall-to-wall
depth = 348 + thickness;    // y = 34.8cm to accomodate 34.8cm tank length
i_height = 195 + thickness; // z = 19.5cm to accomodate 16cm tank height plus wires for shock
                            // (i_height because 'height' is used for height of entire box)

// amount faces extend past each other at corners
overhang = 15;

// amount horizontal support tabs extend past side supports (technically, it will go this distance minus thickness/2)
outset = thickness+2;

// tank base plate
base_height = overhang/2;

// create height var to account for raised base
height = i_height + base_height;

// height of insert for rear tank support
insert_height = height/6;

// hanging support thickness and drop (distance it "sits down" after in place)
support_w = 10;
support_drop = support_w/2;

// useful tank measurements
tank_width = 70;
tank_foot_offset_left = 105;
tank_foot_offset_right = 101;

// x-position of mask piece inside box
mask_loc = tank_width + thickness;  // center-to-center
// dimensions for mask view opening
view_opening_left = 65;
view_opening_right = 78;
view_opening_width = depth-thickness - view_opening_left - view_opening_right;
view_opening_bottom = 24;
view_opening_height = 96;

// camera mounting measurements
camera_hole_diameter = 1.7;       // bolts are m2; 2mm nominal, 1.9mm actual, and a bit less for the beam width
camera_hole_horiz_offset = 21/2;  // 21mm between mounting holes, horizontally (so half that away from the camera center
camera_hole_vert_offset = 12.5;   // 12.5mm between mounting holes, vertically (one set on the camera center, one set up that much from center)

// position of rpi and related parts
rpi_ypos = depth/2 + 60;

// for slight offsets/tweaks
epsilon = 1;

// set precision of all arcs/spheres/cylinders/etc.
$fn = 50;

// vars to control projection for DXF export (see makefile)
if (DXF_TOP) {
    projection() top_cover(spacing=1);
} else if (DXF_BOTTOM) {
    projection() tank_base();
} else if (DXF_SIDE1) {
    projection() rotate(a=[90,0,0]) side(y=0);
} else if (DXF_SIDE2) {
    projection() rotate(a=[90,0,0]) side(y=depth);
} else if (DXF_END1) {
    projection() rotate(a=[0,90,0]) vert_face(x=0);
} else if (DXF_END2) {
    projection() rotate(a=[0,90,0]) vert_face(x=width);
} else if (DXF_MASK) {
    projection() rotate(a=[0,90,0]) mask(x=mask_loc);
} else if (DXF_TANK_SUPPORT) {
    projection() tank_support_layer1();
    projection() translate([tank_width+thickness,0,0]) tank_support_layer2();
} else if (DXF_RPI_SUPPORT) {
    projection() rotate(a=[90,0,0]) rpi_support();
} else if (DXF_REAR_SUPPORT) {
    projection() rotate(a=[90,0,0]) rear_support(1);
    translate([overhang*3,0,0])
    projection() rotate(a=[90,0,0]) rear_support(2);
    translate([overhang*6,0,0])
    projection() rotate(a=[90,0,0]) rear_support(3);
}
else {
    // 3D model
    // components to include (comment out unwanted)
    vert_face(x=0);      // "near face, transparent for monitor
    vert_face(x=width);  // "far" face, with camera, rpi, etc.
    mask(x=mask_loc);
    side(y=0);
    side(y=depth);
    tank_base();
    tank_support();
    rpi_support(x=width, y=rpi_ypos-10, z=height/2);
    mock_rpi(x=width, y=rpi_ypos, z=height/2);
    top_cover();
    rear_support();
}

//////////////////////////////////////////////////////////////////
// Module definitions
//

module mask(x, tab_extra=0) {
    difference() {
        vert_face_base(x, top_offset=thickness, bottom_offset=base_height-thickness);
        side(y=0);
        side(y=depth);
        translate([x-thickness/2, -overhang, 0]) {
            translate([0, 0, 0])
                rounded_truncation(width=overhang-thickness/2, up=false);
            translate([0, depth+overhang+thickness/2, 0])
                rounded_truncation(width=overhang-thickness/2, up=false);
        }
        // opening for tank view
        translate([0,view_opening_left+thickness/2, view_opening_bottom+base_height+thickness/2])
            cube([width, view_opening_width, view_opening_height]);
        // bottom opening for wires
        translate([0, depth-thickness/2, base_height+thickness])
        rotate(a=[0,90,0])
            cylinder(r=10, h=width);
        // top openings for wires (electrical stim)
        translate([0, depth-15, height-thickness/2])
        rotate(a=[0,90,0])
            cylinder(r=5, h=width);
        translate([0, 15, height-thickness/2])
        rotate(a=[0,90,0])
            cylinder(r=5, h=width);
        // tabs for rigidity w/ bottom panel
        cutouts(4,depth-thickness,outset*2,rot=[-90,0,90],trans=[x+thickness/2,depth/2,base_height+thickness/2], extra=tab_extra);
    }
}

module vert_face(x=0) {
    difference() {
        if (x == 0) {
            vert_face_base(0, window_thickness);
        }
        else {
            vert_face_base(x);
        }
        camera_opening();
        // round=false so we get the full width of the piece in the cutout, not reduced because we hit the rounded corner
        rpi_support(x=width+thickness*2, y=rpi_ypos-10, z=height/2+support_drop, round=false);
        translate([thickness+epsilon,0,-insert_height/2])
            rear_support();
        wire_opening();
        power_jack_cutout();
        // CAUTION: OpenSCAD won't let me make a projection of vert_face(x=0)
        //   if tank_base is put after side(y=depth) here... bug.  :(
        tank_base();
        top_cover();
        side(y=0);
        side(y=depth);
        translate([x-thickness/2, -overhang, 0]) {
            translate([0, depth+overhang+thickness/2, 0])
                rounded_truncation(width=overhang-thickness/2, up=false);
            translate([0, 0, 0])
                rounded_truncation(width=overhang-thickness/2, up=false);
        }
    }
}

module vert_face_base(x, face_thickness=thickness, top_offset=0, bottom_offset=0) {
    translate([x-face_thickness/2, -overhang, bottom_offset])
        cube([face_thickness,depth+overhang*2,height-top_offset-bottom_offset]);
}

module rounded_truncation(width, up, rot=[0,0,0]) {
    truncation_height=height/4;
    rotate(a=rot)
    difference() {
        translate([-50,-epsilon,0])
            cube([100, width+2*epsilon, truncation_height]);
        if (up) {
            translate([-50, width/2, 0])
            rotate(a=[0, 90, 0])
                cylinder(d=width, h=100);
        }
        else {
            translate([-50, width/2, truncation_height])
            rotate(a=[0, 90, 0])
                cylinder(d=width, h=100);
        }
    }
}

module camera_opening() {
    translate([width, depth/2, height/2])
    union() {
        cube([thickness*2,10,10], center=true);
        translate([0, camera_hole_horiz_offset, 0])
        rotate(a=[0, 90, 0])
            cylinder(d=camera_hole_diameter, h=100, center=true);
        translate([0, -camera_hole_horiz_offset, 0])
        rotate(a=[0, 90, 0])
            cylinder(d=camera_hole_diameter, h=100, center=true);
        translate([0, camera_hole_horiz_offset, camera_hole_vert_offset])
        rotate(a=[0, 90, 0])
            cylinder(d=camera_hole_diameter, h=100, center=true);
        translate([0, -camera_hole_horiz_offset, camera_hole_vert_offset])
        rotate(a=[0, 90, 0])
            cylinder(d=camera_hole_diameter, h=100, center=true);
    }
}

module rpi_support(x, y, z, round=true) {
    hanging_support(x, y, z, out=4, up=85, round=round);
}
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

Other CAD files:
designs/dist/end1.dxf
designs/dist/tank_baffle_for_shock.dxf
designs/dist/tank_baffle.dxf
designs/old/cut_test2.dxf
designs/cut_test.scad
designs/cut_test2.scad
designs/old/cut_test.dxf
designs/old/cut_test.scad
designs/old/cut_test2.scad

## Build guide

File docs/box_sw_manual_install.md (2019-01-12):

---
title: Manual Box Software Setup
---

# Manual Box Software Setup

Most people will not need to use the following instructions.  They are provided
for anyone who wants to set up the ATLeS box software environment themselves.
The easiest way to install and use the software is to install a provided OS
image.  The following installation steps require that you are comfortable
working in a Linux development environment.

## Installing ATLeS Software

A common setup will install `atles_web.py` on a server (it has been tested
under Linux and Cygwin thus far), while `atles_remote.py` will run on one or
more Raspberry Pi nodes in the experiment boxes.  When installing on a
Raspberry Pi, start with a clean install of
[Raspbian Lite](https://www.raspberrypi.org/downloads/raspbian/).

The following instructions cover installing the software on a Raspberry Pi, and
they were developed and tested on a clean install of Raspbian Stretch Lite
(2018-11-13).

### Software Dependencies

Before installing the software, install the required tools and libraries (many
may already be installed depending on your base system):

    sudo apt install build-essential pkg-config python3-dev python3-pip git rsync

### Downloading ATLeS Software

Clone the ATLeS repository:

    git clone https://github.com/liffiton/ATLeS.git

The ATLeS software will now be in a folder named `ATLeS`.  The following
commands assume you have changed into that directory.

### atles\_remote.py and atles\_box.py

The software that runs on each box to control experiments and connects back to
the server depends on several Python packages that can be installed via apt and
pip.

First install `numpy` and `smbus` (for reading sensor values) with apt:

    sudo apt install python3-numpy python3-smbus

OpenCV can be installed [via pip](https://blog.piwheels.org/new-opencv-builds/)
with dependencies installed first with apt:

    sudo apt install libatlas3-base libwebp6 libtiff5 libjasper1 libilmbase12 libopenexr22 libilmbase12 libgstreamer1.0-0 libavcodec57 libavformat57 libavutil55 libswscale4 libgtk-3-0 libpangocairo-1.0-0 libpango-1.0-0 libatk1.0-0 libcairo-gobject2 libcairo2 libgdk-pixbuf2.0-0
    sudo pip3 install opencv-python-headless

Install the remaining python packages by running:

    sudo pip3 install -r src/requirements_remote.txt

We install using sudo here so that the libraries are available systemwide, as
`atles_remote.py` will be run as root (to be able to control the PWM output).

### atles\_web.py

The server software is normally run on a system separate from the Raspberry
Pi(s) (see [setup](setup)).  However, it can be installed on a Raspberry Pi
alongside the `atles-remote.py`/`atles_box.py` programs for testing or
prototyping purposes.

Install the Python packages required for `atles_web.py` by running:

    pip3 install --user -r src/requirements_web.txt

### Runtime Dependencies

The camera, SSH, and i2c need to be enabled using raspi-config.  Run `sudo
raspi-config` and enable all three under "Interfacing Options."

To use the camera via v4l, the `bcm2835-v4l2` module must be loaded.  For the
i2c interface (for sensors), the `i2c-dev` module must be loaded.  To have the
modules loaded automatically on boot, add each to `/etc/modules`, one per line:

    bcm2835-v4l2
    i2c-dev

Then reboot the Pi.

Alternatively, modprobe can be used to load the modules manually at any time:

    sudo modprobe bcm2835-v4l2
    sudo modprobe i2c-dev

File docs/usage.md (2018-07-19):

---
title: "Using ATLeS"
---

# Using ATLeS

With the ATLeS server running (``src/atles_web.py``), point a browser to ``http://[hostname]:8080/`` to access the web interface.

## Main Interface

The main page will show all of the boxes that are or have been connected:

{:.center}
Main ATLeS web interface

Each box shows:
 * Its name, current status, and the version of the software it is running.
 * Simple statistics on the tracking quality from the last ten trials that box ran.
 * A button for launching a new experiment/trial.
 * A button to see the current view of that box's fishtank through the camera.

## New Experiment Interface

Pressing any "New Experiment" button brings up the following interface for the given box:

{:.center}
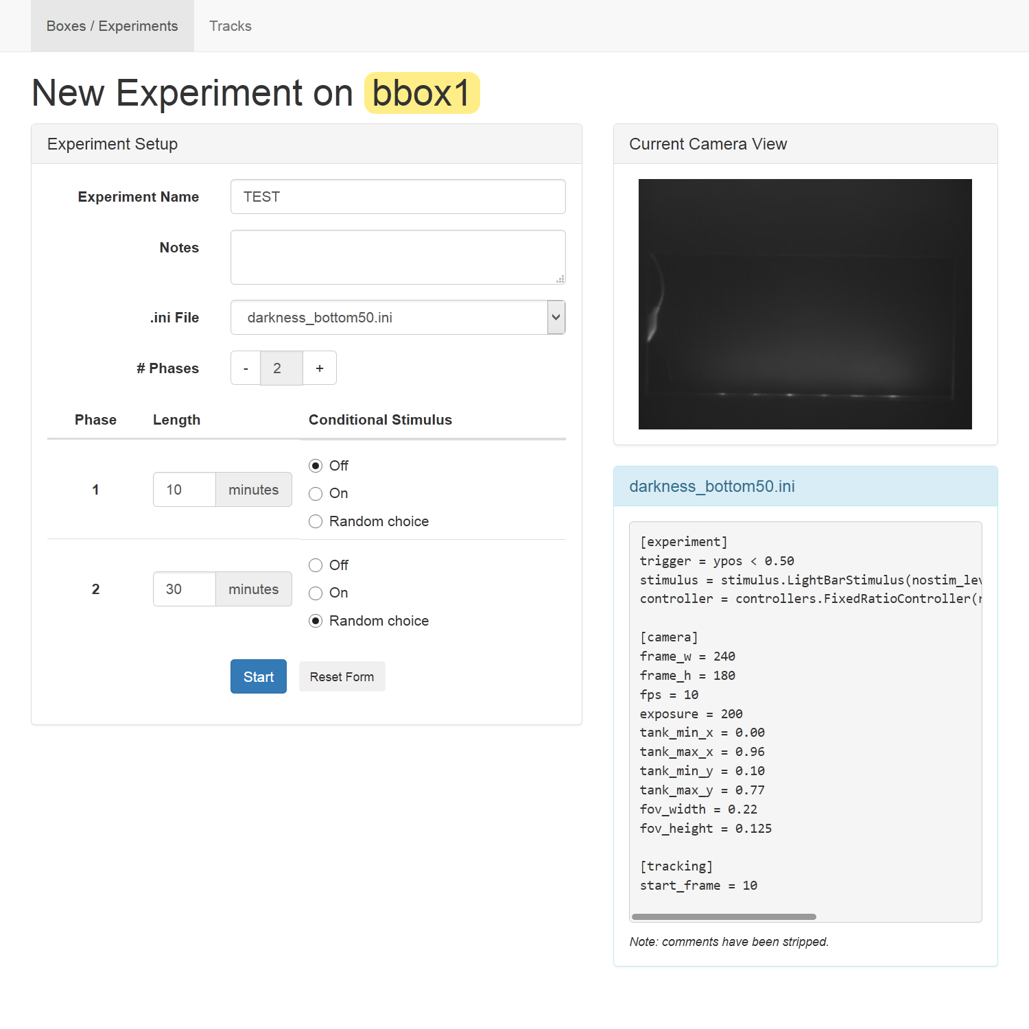
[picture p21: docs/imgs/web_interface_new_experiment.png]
ATLeS new experiment interface


The box in the top right shows a live view from the box's camera.  Use this to verify that a tank and fish are present and that the lighting is appropriate (fully illuminated with no bright spots from glare or reflections).

The details of the experiment to be run are specified on the left.  You can set:
 * The experiment name.  Use the same name across a set of similar experiments for easy grouping and analysis later.
 * Notes on this particular run.  You can use this to differentiate experimental conditions controlled outside of the software such as information about the fish or a drug added to its water.
 * The .ini file -- used to configure the tracking and the experimental stimulus applied.  (See [.ini Files](#inifiles) below.)
 * The phases of the experiment, with a length (in minutes) and whether the stimulus will be on or off for that phase.  "Random choice" means that the system will randomly decide whether the stimulus is active during that phase, with equal probability for on and off.

### .ini Files

The .ini files specify details of an experiment that are constant from trial to trial.  They are saved in the `ini` folder.  The examples included in the repository contain comments explaining what can be set in an .ini file.  Create a new file by copying and modifying one of the examples to suit your setup.

**NOTE:** Currently .ini files must be present both on the server and on all of the box Raspberry Pis.  To manually copy an .ini file to a Pi, use `scp`:

    $ scp file.ini pi@boxhostname:ATLeS/ini/

### Running an experiment

Upon starting an experiment, the main interface will show the status of the experiment including the time remaining.  When an experiment ends, the recorded data will be automatically synced from the Pi to the server.

## Tracks Interface (Collected Data)

The "Tracks" link at the top of the page takes you to a page that lets you view and analyze collected data.

{:.center}
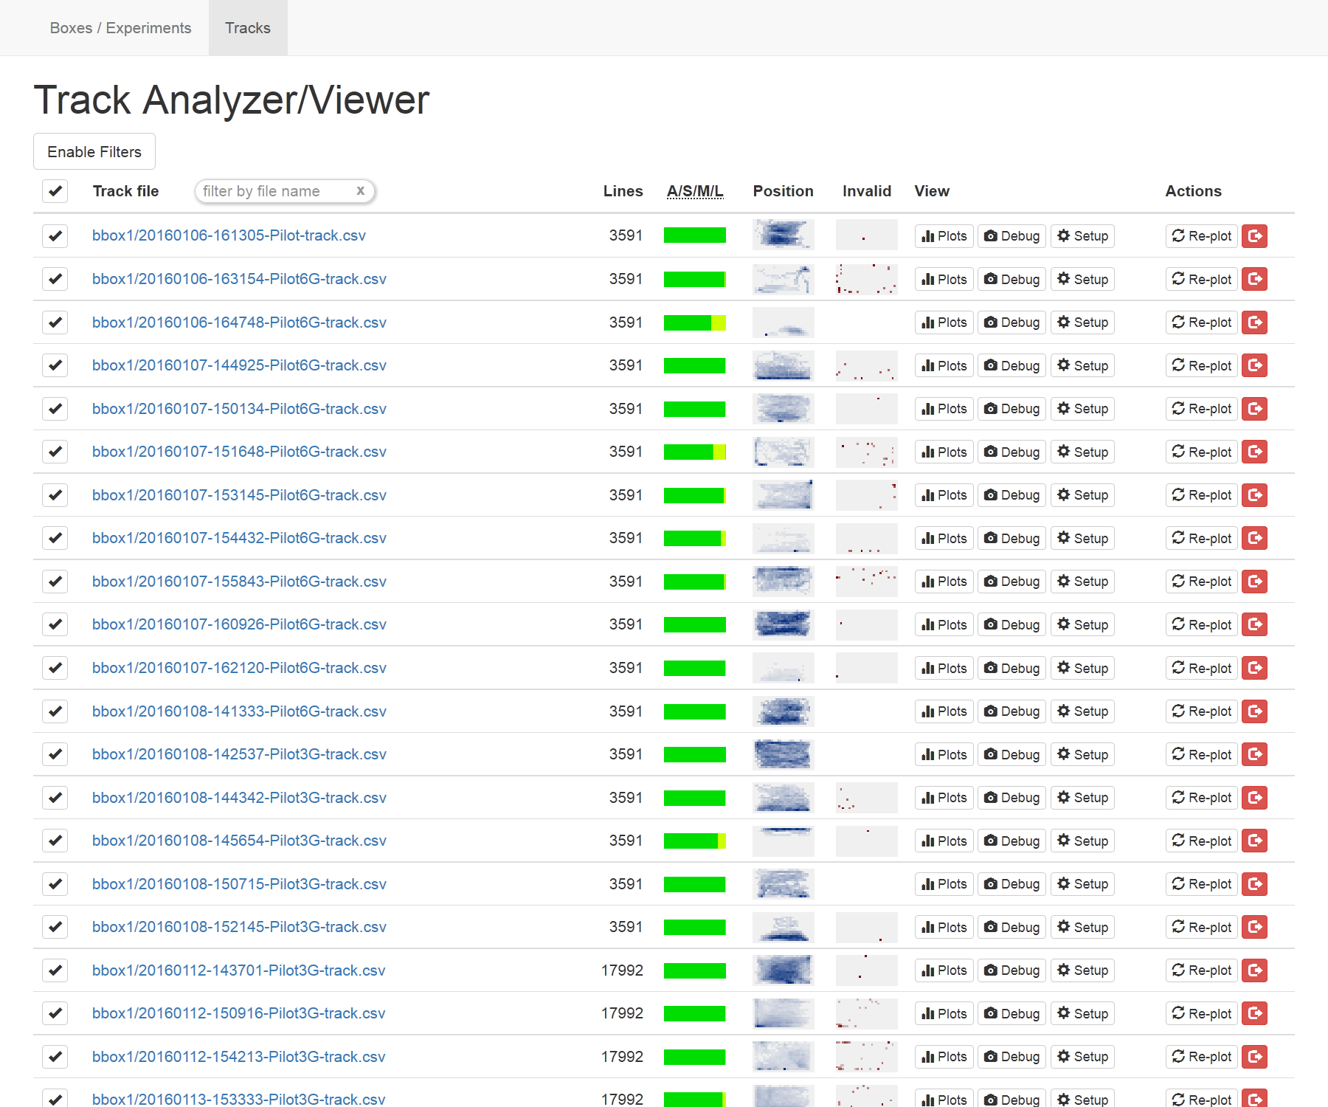
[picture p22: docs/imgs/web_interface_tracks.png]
ATLeS tracks interface


All collected tracks are shown by default.  Press "Enable Filters" to filter the shown tracks by attributes like experiment name, length, tracking quality, etc.  A quick filter based on the filenames is also available in the table header.

Each row of the table contains:
 * The name of the track file with a link to its raw data.
 * The number of lines in the file (as a quick indicator of the length of that track).
 * An "A/S/M/L" chart showing what percentage of the points in the track have the status "Acquired", "Sketchy", "Missing", or "Lost".  "Sketchy" points are those in which the tracking identified more than one point and chose the best one (nearest to the last known position of the fish).  "Missing" and "Lost" are both for times at which no fish was found; the status will first become "Missing" and then "Lost" after 5 tracking frames with no fish found.
 * A "position" heatmap showing where in the tank the fish was over the course of the entire experiment.
 * An "invalid" heatmap showing where in the tank the fish was before it was ever missing or lost; this can help identify common locations where tracking fails, if any.
 * Buttons to view plots, debug frames, and setup files (described below).
 * Buttons to re-create the plots for a track and to archive it (hide it from this view, though the file is retained on the system).

Some or all of the displayed tracks can be selected using the checkmarks in the leftmost column, and actions to be taken on the selected tracks (described below) are available at the bottom of the page.

### Plots

The ATLeS software can generate plots visualizing the data in a track.

{:.center}
ATLeS plots 1

First are a variety of position heatmaps.  The "Overall heatmap" shows where the fish was over the entire track, and the "Map of shame" shows locations where tracking failed.  Position heatmaps for each phase and for each minute of the experiment follow.

{:.center}
ATLeS plots 2

Plots visualizing the time series data show:
 * The location of the fish over time (as separate plots of its X- and Y- coordinate at each time)
 * The number of points detected at each time (1 is good, 2 or more is "sketchy", and 0 is "missing" or "lost")
 * When the tracking status was "missing" or "lost", indicated by yellow and red bars along the bottom of the plot
 * Whether the fish was "frozen" at any point, indicated by a blue bar along the bottom of the plot

Additionally, small blue dots are placed along the x-axis of the plot.  Each indicates a time at which a debug frame was recorded.  Mouse over the dot to view the frame captured at that time.

### Debug Frames

For debugging purposes, ATLeS records the current frame (whatever it's seeing through the camera) at a regular interval as well as whenever it first loses tracking (entering the "missing" state).  These can be viewed individually in the Plots view as described above or viewed all together on one page by choosing the "Debug" button for any track.

The first frame is shown with the entire view of the camera, and "subframes," the cropped and grayscale images used in the actual tracking, are shown for later frames.  Press "+" to increase the brightness of all displayed frames; this helps make out faint features.

### Setup Files

Each setup file contains all of the details of how that experiment for that track was run.  This includes all of the information from the chosen .ini file for that track plus anything set in the "New Experiment" interface.  This file can provide metadata to be used in analyses of track files.  For example, it allows you to differentiate between trials where the "Random" stimulus was chosen to be active and those where it was not.

### Selection Actions

When one or more track files are selected using the checkboxes in the main Tracks view, the actions at the bottom will become available:

#### Filter

Filter the view so that only the selected tracks remain.

#### Generate aggregate heatmaps

Generates heatmaps for each phase of an experiment over all selected tracks.  That is, one heatmap will be generated for the first phase of the experiment showing the locations of all of the fish in all of the selected tracks, one for the second phase, etc.  This requires that all selected tracks share the same phase lengths.

#### Download raw data [.zip]

Download a .zip archive containing all of the selected tracks and their setup files.

#### Re-plot

Regenerate the plots for all selected tracks (or generate them for the first time if they haven't been created yet).

#### Archive

Archive all of the selected tracks (hides them, but the files still remain in the `data` directory under `data/tracks_archive`).

#### Statistics

These actions calculate a large number of statistics for the selected tracks and produce a table with one row per track and one column per calculated statistic.  They can be viewed in the browser or downloaded as a .csv file.  The "(extinction)" variants produce calculations specific to a learning/extinction experiment.

## Further Analysis

A Jupyter notebook demonstrating deeper analysis of track data can be found in the `notebooks` directory.  View it on Github [here](https://github.com/liffiton/ATLeS/tree/master/notebooks), including a link to run a live, editable version of the notebook with some of our experimental data.

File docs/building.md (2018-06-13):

---
title: "Building an ATLeS Box Enclosure"
---

# Building an ATLeS Box Enclosure

The `designs` folder in the ATLeS repository contains source files for nearly all of the parts required to build an ATLeS box enclosure.  In the `designs/box/box_structure.scad` is an [OpenSCAD](http://www.openscad.org/) 3D model of the enclosure.

DXF files suitable for laser-cutting are provided in `designs/dist`.  They can be re-created from the OpenSCAD source using `make` (requires OpenSCAD).

The enclosure was designed to be laser cut from 1/8" [hardboard](https://en.wikipedia.org/wiki/Hardboard).  Other sheet materials suitable for laser cutting (e.g. plywood or acrylic) may work with small modifications to the design to account for different material thickness.

## Build Walkthrough

All of the DXF files in `designs/dist` should be laser cut out of opaque material *except* `tank_support.dxf`, which is meant to be clear acrylic (so the infrared illumination below it reaches the tank above).  The `tank_baffle*.dxf` and `tank_lid*.dxf` files are not part of the enclosure, but rather they are designed to be used in a particular model of fish tank.

### Step 1
To start, slot the bottom sheet `bottom.dxf` into the slots on the two end pieces `end1.dxf` and `end2.dxf`:

{:.center}
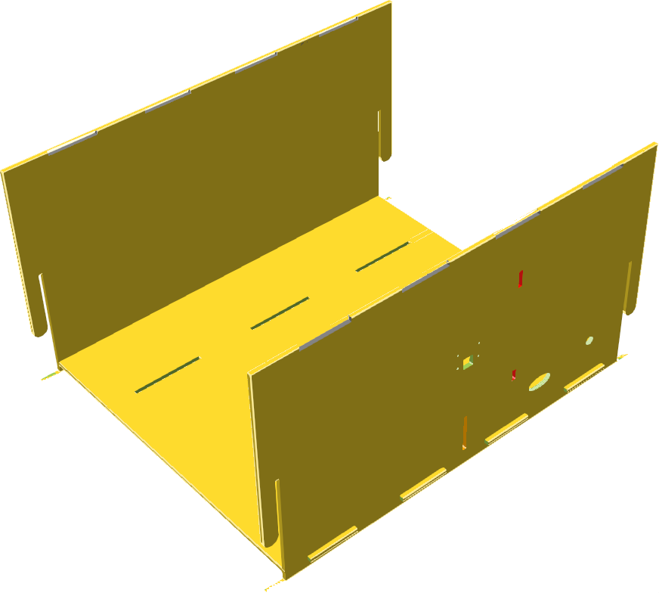
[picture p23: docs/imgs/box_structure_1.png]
Build step 1
<br>
Build step 1

### Step 2
Next, slide the two side pieces `side1.dxf` and `side2.dxf` into the slots on the edges of the end pieces to form a box:

{:.center}
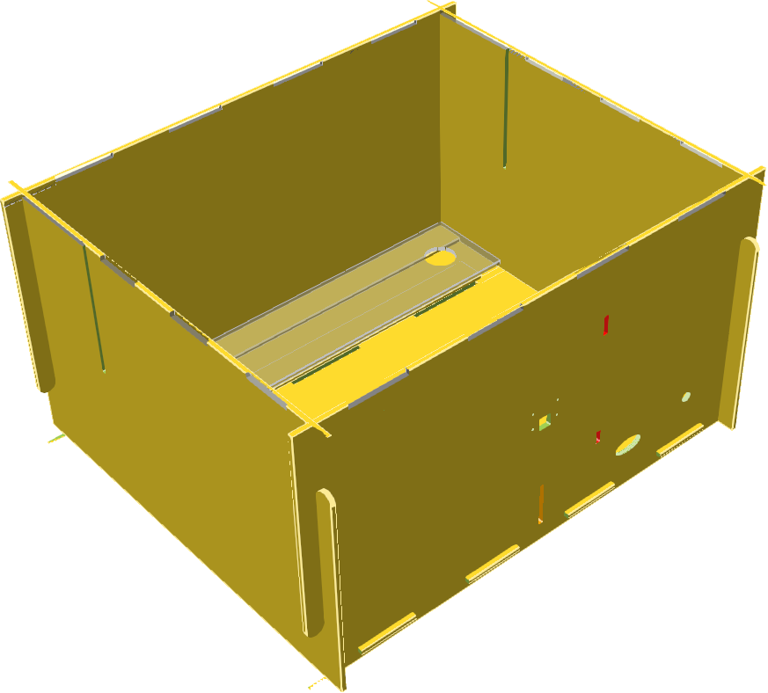
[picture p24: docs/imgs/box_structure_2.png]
Build step 2
<br>
Build step 2

The above image also shows the placement of the clear acrylic tank support pieces.  The two thin pieces are on the bottom, with room between for the strip of infrared lights, and the larger piece covers them and provides a platform for the fish tank.

### Step 3
The mask piece `mask.dxf` slides in from the top, interfacing with the two sides:

{:.center}
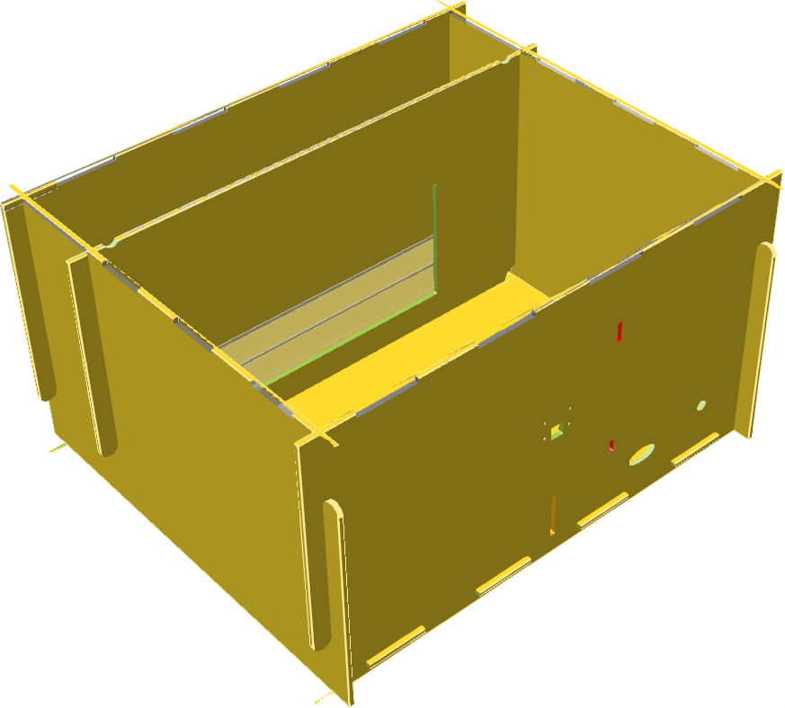
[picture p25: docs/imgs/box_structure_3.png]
Build step 3
<br>
Build step 3

### Step 4
The two top pieces `top.dxf` fit into place on top of the box (they are translucent here but should be opaque in reality), and the support bracket for the Raspberry Pi holds it in place as shown:

{:.center}
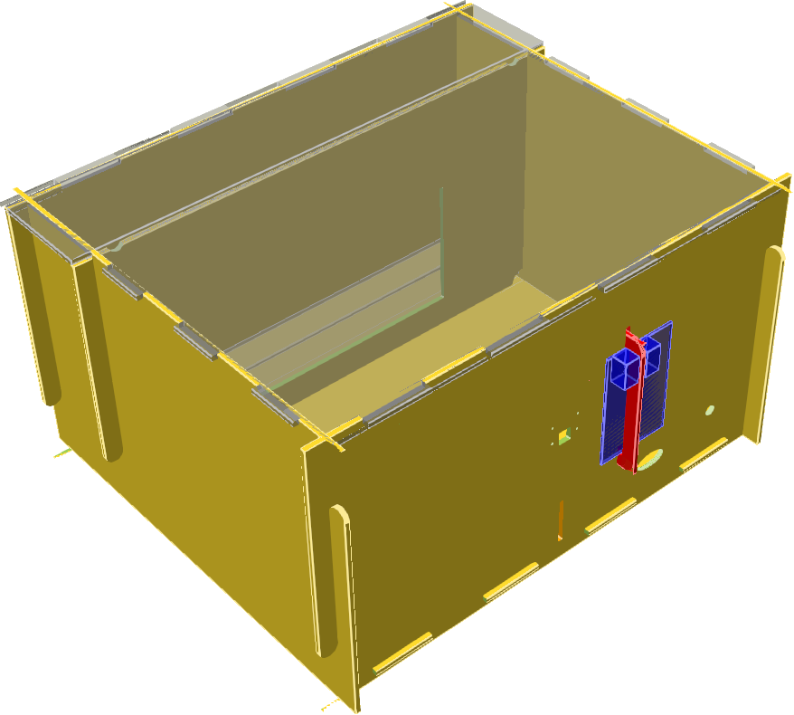
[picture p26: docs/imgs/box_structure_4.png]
Build step 4
<br>
Build step 4

The camera mounts using M2 standoffs and screws.  The circular hole in the back piece is for mounting a 2.5mm DC jack for power, and the wider, elliptical hole is for passing wires through from the Raspberry Pi to the electronics inside.

### Step 5 (only if stacking)
Enclosures can be stacked up to three high, with each offset to the rear from the one below to allow access to load fish tanks into each.  In this case, a rear support piece can be added at the vertical slit on the rear of any box whose back is now unsupported:

{:.center}
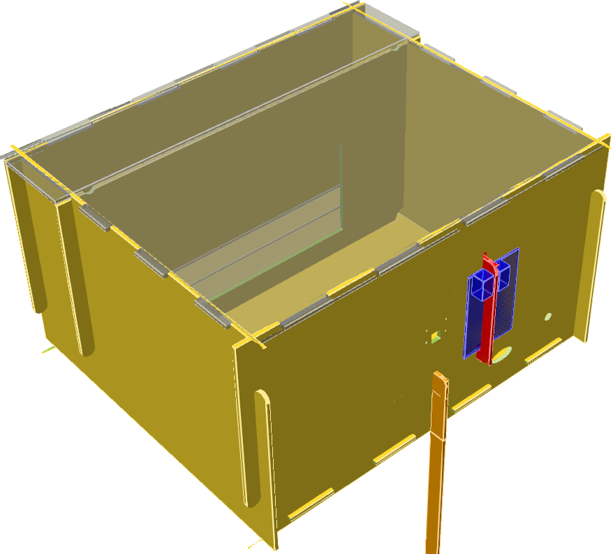
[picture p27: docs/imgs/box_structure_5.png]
Build step 5
<br>
Build step 5 (optional)

Adjust the length of the support piece as needed to reach the surface below.

# Electronics

The electronics require some wiring.  Knowledge and experience with electronics is helpful.

{:.center}
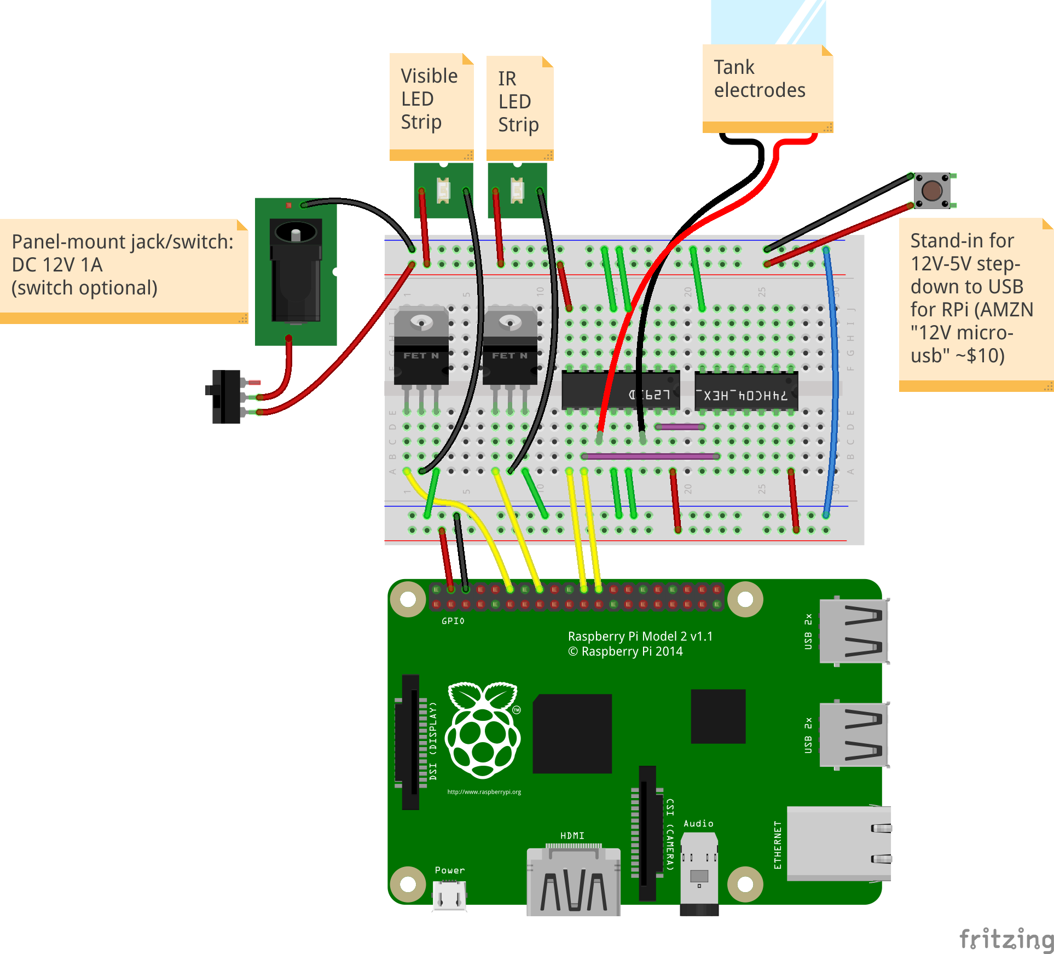
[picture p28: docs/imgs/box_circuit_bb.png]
The main breadboard
<br>
The main breadboard

The above image shows the connections that need to be made.  The source file, made with [Fritzing](http://fritzing.org/), is available in `designs/circuit/box_circuit.fzz`.

Our [bill-of-materials spreadsheet](https://docs.google.com/spreadsheets/d/1JdE_qXsXnkHEHv3YeQ8cLeGDJKUJM5uZkHw2dTtAtYg/edit?usp=sharing) lists the required parts along with estimated costs and links to options for purchasing most of them.

Everything should be powered from a 12VDC supply that can provide at least 1A of current.  Via a jack, wire the 12VDC to the top blue and red rails of the breadboard as shown.  **NOTE** that only the ground (blue) rail is shared with the bottom; the bottom red rail is 5VDC provided by the Raspberry Pi.

The Pi is powered with 5VDC over a micro-USB connection.  Many 12V to 5V micro-USB converters are available on Amazon (the bill of materials contains a link to one).

A strip of white, visible-light LEDs should be installed along the top of the back wall of the enclosure (where the camera is mounted), and a strip of infrared LEDs should be mounted on the bottom of the enclosure below where the fish tanks will be placed.  The positive/power lead of each strip is connected to the +12VDC rail, while the negative/ground for each connects to an N-type power MOSFET on the breadboard so it can be controlled by the Pi.  The other pins of each MOSFET are connected to ground and to a specific GPIO pin on the Pi (the software has those pin numbers hard-coded).

If using electrical stimulus in the fish tanks, suitable electrodes (large pieces of ideally non-reactive metal) should be placed at each end of the tank and each wired back to the breadboard.  In our current design, they are driven by an L293D dual H-bridge motor controller.  We use a standard 7400-series hex inverter chip alongside that.

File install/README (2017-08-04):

To install atles_web.py as a systemd service:

 1. Edit atles_web.service to set the correct values for the "User," "Group,"
    "WorkingDirectory," and "ExecStart," values in the [Service] section.

 2. Copy the atles_web.service file to /etc/systemd/system/ directory.

 3. Test running the service:
    sudo systemctl start atles_web

 4. If it works (you can access the web server with a browser), enable the service on boot:
    sudo systemctl enable atles_web

To setup a remote ATLeS box Raspberry Pi:

 1. Run "./setup_box.sh MACHINENAME" with the hostname of the Pi.

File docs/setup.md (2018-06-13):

---
title: "System Integration & Setup"
---

# Installation / Setup

A complete ATLeS installation consists of an ATLeS server and one or more ATLeS boxes on the same network as the server.

## Network Setup

Only the server needs to be accessible to other machines.  For security purposes, the boxes should ideally be on an isolated private network that connects only the boxes and the server, but this is not strictly required.  
The minimum requirement for the software to work correctly (finding and registering boxes in the server interface) is that the server and the boxes are on the same subnet / broadcast domain.

The Raspberry Pi systems controlling the boxes should not be considered strongly secured, and separating them from other networks is ideal.  One way to achieve this security and separation is to install the server on a machine with two network interfaces: one connects to the regular campus/business network, while the other connects to a separate switch along with all of the ATLeS boxes.

### Without a Separate Server

The server software *can* run on a Raspberry Pi, even one installed in and controlling an ATLeS box, and so it is possible to create a working system with even just a single Raspberry Pi.  This is **not recommended** due to security, performance, and stability issues that may arise.  However, it can provide a quick, relatively simple way to prototype or demonstrate ATLeS.

## ATLeS Server

The server software has been tested under Debian Linux and Cygwin.  It should work on any recent Linux distribution, and it may run on other platforms as well.

To install the server software, first clone the [ATLeS repository](https://github.com/liffiton/ATLeS):

    git clone https://github.com/liffiton/ATLeS.git

Required Python packages can be installed using pip (`pip3` is used as ATLeS is written for Python 3).  If you need to install pip, refer to [these instructions](https://pip.pypa.io/en/stable/installing/).

    cd ATLeS/src
    pip3 install --user -U -r requirements_web.txt

The `--user` flag installs the required packages for the current user only.  Alternatively, you can install them and run ATLeS within a [virtual environment](https://docs.python.org/3/library/venv.html) or install them systemwide by omitting `--user` and adding `sudo` before the `pip3` command.

If pip installs the required packages successfully, you should be able to run the server:

    ./atles_web.py

By default, it will start serving the web interface on port 8080 (configurable via the `--port` command line option), and it will be accessible by pointing a web browser to http://1.2.3.4:8080/, where 1.2.3.4 is replaced with the IP address of the server.

## ATLeS Box

### Installing the Software

The easiest way to install the required software on a Raspberry Pi for a new
ATLeS Box is to burn (write) a pre-configured image onto a MicroSD card.  A 4GB
card is required, and 8GB or larger is recommended.  Disk images are available
as versioned releases on Github:
[https://github.com/liffiton/ATLeS/releases](https://github.com/liffiton/ATLeS/releases).
Download a disk image and extract the .img file.  We recommend using
[Etcher](https://etcher.io/) to burn the image to a MicroSD card.

Alternatively, follow the [Manual Box Software Setup](box_sw_manual_install) instructions to install all needed software from scratch.

### Setting Up a Newly-Cloned Raspberry Pi

If using a provided pre-configured image to install the software, a few additional steps are required.

Boot and log in to the Raspberry Pi with a freshly-installed MicroSD card with username: `pi` password: `fishypi`.

If the Pi will be on a publicly-accessible network, change the password to something secure by running `passwd`.

Run `sudo raspi-config` and:

  1. Expand filesystem to fit (depending on the image you used, this may have been done automatically already)

  2. Set hostname (suggestion: name boxes sequentially and label each box with its hostname -- this is how they will be identified in the web interface)

Exit the configuration software and reboot.

After rebooting the box, there is one more step to register the box on the
server.  From the **server**, run:

    ATLeS/install/setup_box.sh [box hostname or IP]

You will need to provide a password to log in to the box (the default from
above or whatever you set it to), and it will then setup the box to run the
`atles_remote.py` software at boot.

Now, if the box is connected to the same network as the server, the box should
appear in the web interface automatically.

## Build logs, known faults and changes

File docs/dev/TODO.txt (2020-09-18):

TODOs and Plans
===============

ATLeSweb / Analyze
------------------
 - :!: Convert plotting from pyplot to object-oriented interface.  (Test
   whether that fixes the corrupted plots produced when asking the web
   interface to plot multiple tracks at once.)
 - :?: When does the data output/recording start?  How is that indicated?
 - Experiment progress indicator should know when timing actually started

Box Setup
---------
 - Simplify and automate box setup/installation with Ansible.
 - Package ATLeS software for distribution on PyPI (_web and _box separately).

ATLeS Box Image
---------------
 - https://github.com/Drewsif/PiShrink/

Enclosure
---------
Wait on these until we start looking at monitor stimulus again:
 - Integrate frameless LCD display
 - Add cable routing for HDMI, etc.

Circuits
--------
 - Any way to assemble the circuits w/o soldering?  Currently, the headers have to be soldered on the sensors.
   * Sensors sold w/ headers pre-soldered?
   * Other ways of making connections to the 0.1" spaced holes?

ATLeSbox [.py]
--------------

Big / Important:
 - Switch to pigpio library for PWM -- runs separate daemon as root, all rest
   as unprivileged user.
   - OR switch to latest kernel w/ /dev/gpiomem access... see if wiringpi will use it.
 - Make background subtractor adaptive, modifying sensitivity to hit 1
   detection exactly. (See babyfish code.)

Medium:
 - Utility to create an .ini file interactively (w/ camera view, clicking,
   etc.)
 - Save video (if possible)
 - Report m/s velocities in analyze.py (requires figuring out best way to get
   different position data (frame- and tank-coords and tank phys size) into
   analyze.py...)

Testing/validation:
 - Check carefully how invalid entries ['lost'] will affect collected metrics

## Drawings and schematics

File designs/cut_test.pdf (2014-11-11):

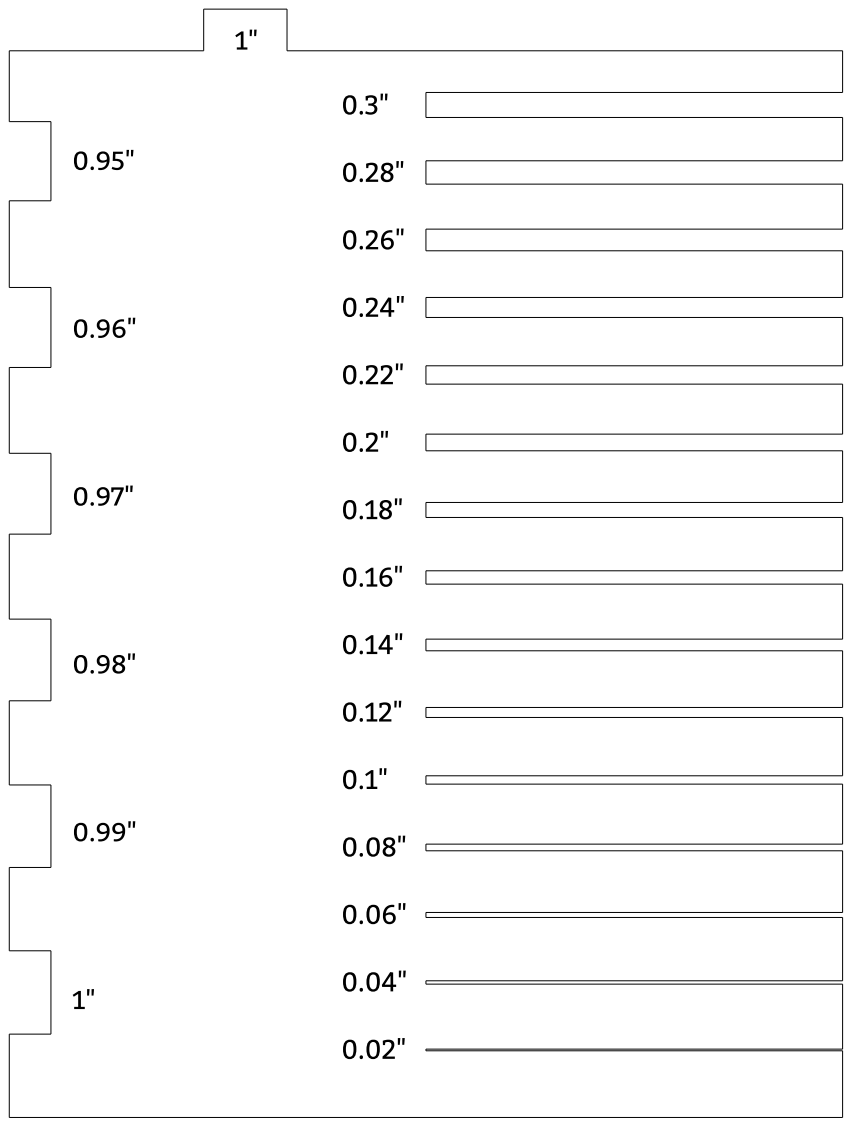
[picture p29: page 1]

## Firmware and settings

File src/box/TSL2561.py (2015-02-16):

# TSL2561.py - A class for using the TSL2561 chip via the i2c bus
# Author: Mark Liffiton
# Date: January, 2015
### Adapted from:
###   https://github.com/seanbechhofer/raspberrypi/tree/master/python

from Adafruit_I2C import Adafruit_I2C
import time

# Constants
_default_address = 0x39
_control_command = 0x80
_timing_command  = 0x81
_read_ir_vis_command  = 0xAC
_read_ir_only_command = 0xAE


class TSL2561(object):
    i2c = None

    def __init__(self, address=_default_address, debug=False):
        self._debug = debug
        self.i2c = Adafruit_I2C(address, debug=debug)
        self.power_up()
        self._gain = -1  # don't know gain to start (board may be powered and configured)
        self.set_gain(1)

    def power_up(self):
        ''' Send byte 0x03 to Control register (0h). '''
        self.i2c.write8(_control_command, 0x03)

    def power_down(self):
        ''' Send byte 0x00 to Control register (0h). '''
        self.i2c.write8(_control_command, 0x00)

    def set_gain(self, gain=1):
        """ Set the gain.

        Arguments:
        gain -- The new gain value.  Gain is set to 1x if gain=1, 16x otherwise.  (Default=1)
        """
        if (gain != self._gain):
            if (gain == 1):
                self.i2c.write8(_timing_command, 0x02)  # set gain = 1X and timing = 402 ms
            else:
                self.i2c.write8(_timing_command, 0x12)  # set gain = 16X and timing = 402 ms

            self._gain = gain                           # save gain for calculation

            # store when new integration will be done (> 402 ms away)
            # 0.8 found to work experimentally
            # 0.402 and even 0.5 too short, give incorrect first readings sometimes
            self._integration_done = time.time() + 0.8

    def _wait_for_integration(self):
        ''' Wait for integration to complete if gain has been reset / new integration ongoing '''
        timeleft = self._integration_done - time.time()
        if timeleft > 0:
            time.sleep(timeleft)

    def read_full(self):
        ''' Read visible+IR value from the device '''
        self._wait_for_integration()
        return self.i2c.readU16(_read_ir_vis_command)

    def read_IR(self):
        ''' Read IR only value from the device '''
        self._wait_for_integration()
        return self.i2c.readU16(_read_ir_only_command)

    def read_lux(self):
        ''' Read both values and calculate a lux measurement '''
        full = self.read_full()
        IR = self.read_IR()

        if self._gain == 1:
            full *= 16    # scale 1x to 16x
            IR *= 16      # scale 1x to 16x

        # avoid divide-by-zero
        if full == 0:
            return 0

        ratio = (IR / float(full))  # changed to make it run under python 2

        if ((ratio >= 0) & (ratio <= 0.52)):
            lux = (0.0315 * full) - (0.0593 * full * (ratio**1.4))
        elif (ratio <= 0.65):
            lux = (0.0229 * full) - (0.0291 * IR)
        elif (ratio <= 0.80):
            lux = (0.0157 * full) - (0.018 * IR)
        elif (ratio <= 1.3):
            lux = (0.00338 * full) - (0.0026 * IR)
        elif (ratio > 1.3):
            lux = 0

        return lux

if __name__ == "__main__":
    tsl = TSL2561(debug=True)
    lux = tsl.read_lux()
    print "%0.3f lux" % lux

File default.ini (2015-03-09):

# Configuration options for fishbox.py
#
# Modify this file to match your physical setup.

# Camera setup
[camera]
# Tank positioning shold be given in terms of normalized 0.0-1.0 ranges
# Specify the minimum and maximum x- and y-extents of the fishtank within the image captured by the camera.
tank_min_x = 0.02
tank_max_x = 0.95
tank_min_y = 0.08
tank_max_y = 0.72
# Measure the field of view of the camera at the distance of the fishtank's centerpoint.
# Measurements should be given in meters.
fov_width = 0.22
fov_height = 0.125

# Stimulus window positioning
# Place and size the stimulus window to cover a whole face of the fishtank.
[stimulus]
# x and y coordinates of window; 0,0 is top left; -1 will place window at right or bottom of screen
x = -1
y = -1
# width and height of window
width = 1200
height = 800

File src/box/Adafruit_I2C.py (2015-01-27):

#!/usr/bin/python
import re
import smbus

### Source (2015-01-27):
###   https://github.com/adafruit/Adafruit-Raspberry-Pi-Python-Code/tree/master/Adafruit_I2C

# ===========================================================================
# Adafruit_I2C Class
# ===========================================================================

class Adafruit_I2C(object):

  @staticmethod
  def getPiRevision():
    "Gets the version number of the Raspberry Pi board"
    # Revision list available at: http://elinux.org/RPi_HardwareHistory#Board_Revision_History
    try:
      with open('/proc/cpuinfo', 'r') as infile:
        for line in infile:
          # Match a line of the form "Revision : 0002" while ignoring extra
          # info in front of the revsion (like 1000 when the Pi was over-volted).
          match = re.match('Revision\s+:\s+.*(\w{4})$', line)
          if match and match.group(1) in ['0000', '0002', '0003']:
            # Return revision 1 if revision ends with 0000, 0002 or 0003.
            return 1
          elif match:
            # Assume revision 2 if revision ends with any other 4 chars.
            return 2
        # Couldn't find the revision, assume revision 0 like older code for compatibility.
        return 0
    except:
      return 0

  @staticmethod
  def getPiI2CBusNumber():
    # Gets the I2C bus number /dev/i2c#
    return 1 if Adafruit_I2C.getPiRevision() > 1 else 0

  def __init__(self, address, busnum=-1, debug=False):
    self.address = address
    # By default, the correct I2C bus is auto-detected using /proc/cpuinfo
    # Alternatively, you can hard-code the bus version below:
    # self.bus = smbus.SMBus(0); # Force I2C0 (early 256MB Pi's)
    # self.bus = smbus.SMBus(1); # Force I2C1 (512MB Pi's)
    self.bus = smbus.SMBus(busnum if busnum >= 0 else Adafruit_I2C.getPiI2CBusNumber())
    self.debug = debug

  def reverseByteOrder(self, data):
    "Reverses the byte order of an int (16-bit) or long (32-bit) value"
    # Courtesy Vishal Sapre
    byteCount = len(hex(data)[2:].replace('L','')[::2])
    val       = 0
    for i in range(byteCount):
      val    = (val << 8) | (data & 0xff)
      data >>= 8
    return val

  def errMsg(self):
    print "Error accessing 0x%02X: Check your I2C address" % self.address
    return -1

  def write8(self, reg, value):
    "Writes an 8-bit value to the specified register/address"
    try:
      self.bus.write_byte_data(self.address, reg, value)
      if self.debug:
        print "I2C: Wrote 0x%02X to register 0x%02X" % (value, reg)
    except IOError, err:
      return self.errMsg()

  def write16(self, reg, value):
    "Writes a 16-bit value to the specified register/address pair"
    try:
      self.bus.write_word_data(self.address, reg, value)
      if self.debug:
        print ("I2C: Wrote 0x%02X to register pair 0x%02X,0x%02X" %
         (value, reg, reg+1))
    except IOError, err:
      return self.errMsg()

  def writeRaw8(self, value):
    "Writes an 8-bit value on the bus"
    try:
      self.bus.write_byte(self.address, value)
      if self.debug:
        print "I2C: Wrote 0x%02X" % value
    except IOError, err:
      return self.errMsg()

  def writeList(self, reg, list):
    "Writes an array of bytes using I2C format"
    try:
      if self.debug:
        print "I2C: Writing list to register 0x%02X:" % reg
        print list
      self.bus.write_i2c_block_data(self.address, reg, list)
    except IOError, err:
      return self.errMsg()

  def readList(self, reg, length):
    "Read a list of bytes from the I2C device"
    try:
      results = self.bus.read_i2c_block_data(self.address, reg, length)
      if self.debug:
        print ("I2C: Device 0x%02X returned the following from reg 0x%02X" %
         (self.address, reg))
        print results
      return results
    except IOError, err:
      return self.errMsg()

  def readU8(self, reg):
    "Read an unsigned byte from the I2C device"
    try:
      result = self.bus.read_byte_data(self.address, reg)
      if self.debug:
        print ("I2C: Device 0x%02X returned 0x%02X from reg 0x%02X" %
         (self.address, result & 0xFF, reg))
      return result
    except IOError, err:
      return self.errMsg()

  def readS8(self, reg):
    "Reads a signed byte from the I2C device"
    try:
      result = self.bus.read_byte_data(self.address, reg)
      if result > 127: result -= 256
      if self.debug:
        print ("I2C: Device 0x%02X returned 0x%02X from reg 0x%02X" %
         (self.address, result & 0xFF, reg))
      return result
    except IOError, err:
      return self.errMsg()

  def readU16(self, reg, little_endian=True):
    "Reads an unsigned 16-bit value from the I2C device"
    try:
      result = self.bus.read_word_data(self.address,reg)
      # Swap bytes if using big endian because read_word_data assumes little 
      # endian on ARM (little endian) systems.
      if not little_endian:
        result = ((result << 8) & 0xFF00) + (result >> 8)
      if (self.debug):
        print "I2C: Device 0x%02X returned 0x%04X from reg 0x%02X" % (self.address, result & 0xFFFF, reg)
      return result
    except IOError, err:
      return self.errMsg()

  def readS16(self, reg, little_endian=True):
    "Reads a signed 16-bit value from the I2C device"
    try:
      result = self.readU16(reg,little_endian)
      if result > 32767: result -= 65536
      return result
    except IOError, err:
      return self.errMsg()

if __name__ == '__main__':
  try:
    bus = Adafruit_I2C(address=0)
    print "Default I2C bus is accessible"
  except:
    print "Error accessing default I2C bus"

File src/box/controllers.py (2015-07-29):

import time


class Controller(object):
    def __init__(self):
        self._hits = []
        self._response = 1  # static response for now

    def add_hit(self, hit):
        new_hit = {
            'time': time.time(),
            'hit': hit,
        }
        self._hits.append(new_hit)


class FixedRatioController(Controller):
    def __init__(self, response_step):
        '''response_step (int): #hits between responses (1 = every hit)'''
        super(FixedRatioController, self).__init__()
        self._step = response_step

    def get_response(self):
        if len(self._hits) % self._step == 0:
            return self._response
        else:
            return 0  # 0 = no stimulus


class FixedIntervalController(Controller):
    def __init__(self, response_interval):
        '''response_interval (int): min seconds between responses'''
        super(FixedIntervalController, self).__init__()
        self._interval = response_interval
        self._prevtime = None

    def get_response(self):
        curtime = self._hits[-1]['time']

        if self._prevtime is None or (curtime - self._prevtime) >= self._interval:
            self._prevtime = curtime
            return self._response
        else:
            return None

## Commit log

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2014-03-15 Cleaned things up, implemented a much simpler, clearer tracker, which is fine for this mostly noiseless situation.
    [tracking.py]
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2014-06-12 Improve fps reporting for camtest.py, avoid overhead of too-frequent printing.
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2014-07-01 Add command line options, improve startup of stimulus (so isn't started if argparsing fails, e.g.)
    [experiment.py, stimulus.py]
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2014-07-25 Fix to show no stimulus in cases when behavior test is false.
    [experiment.py]
2014-07-27 Move and rename some text files.
    [fishybox.skp]
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2014-08-03 Switch to gradient (slightly diff results...) for no worries about off-by-one, missing values, etc.
2014-08-04 Invert y-axis for scaled/saved position data.
    [tracking.py]
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2014-08-04 Show missing/lost as different color.
    [experiment.py]
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2014-09-26 First shot at a camera enclosure design or two.
    [piCameraEnclosure.scad, piCameraEnclosure.stl, piCameraEnclosureFiltered.scad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]
2014-09-29 Record sources, grab initial RPI case design.
    [RaspberryPi_v15.scad]
2014-09-29 First printed Pi enclosure.
    [RaspberryPi_v15.scad, RaspberryPi_v15.stl]
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2014-09-30 Tweak rpi enclosure design. Still need correct outlet for camera cable.
    [RaspberryPi_v15.scad]
2014-10-01 Several tweaks. Fit camera cable. Add some space here and there. Etc.
    [RaspberryPi_v15.scad]
2014-10-01 Updates to pi enclosure for better fit. Removed .makerbot files from repo.
    [RaspberryPi_v15.scad, RaspberryPi_v15.stl]
2014-10-01 More tweaks. Always tweaks.
    [RaspberryPi_v15.scad, RaspberryPi_v15.stl]
2014-10-01 Separate top and bottom parts for pi enclosure.
    [RaspberryPi_v15_bottom.stl, RaspberryPi_v15_top.stl]
2014-10-01 Drop any mention of feet or inlets, neither of which we'll want.
    [RaspberryPi_v15.scad]
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2014-10-04 Removed enclosure w/ filter spot.
    [piCameraEnclosureFiltered.scad, piCameraEnclosureFiltered.stl]
2014-10-04 Updates to camera enclosure: rounded corners, better(?) clearances, indent in cover...
    [piCameraEnclosure.scad, piCameraEnclosure.stl]
2014-10-05 Tweak placement of cover.
    [piCameraEnclosure.scad]
2014-10-05 Tweak holes, add LED holes, make PCB transparent.
    [RaspberryPi_v15.scad]
2014-10-06 Replace os.system w/ subprocess.call.
    [tracking.py]
2014-10-06 Add mouse interaction to --watch mode, fix zero-area countour crash.
    [experiment.py, tracking.py]
2014-10-10 Clearance tweaks based on recent print.
    [piCameraEnclosure.scad]
2014-10-12 Slow down estimated velocity while fish is missing.
    [tracking.py]
2014-10-12 Start of a first attempt at a complete enclosure design in openscad.
    [fishbox.scad]
2014-10-13 Further work on box/enclosure design.
    [fishbox.scad]
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2014-10-14 Strip clearance (use thickness), add light bar, fix width/length/depth, simplify code.
    [fishbox.scad]
2014-10-14 Cleanup / reorganize docs.
    [fishybox.skp]
2014-10-14 Clean up parameters, units, etc.
    [fishbox.scad]
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2014-10-15 Fixed the heatmap... I think. (matplotlib switches y, x... I think.)
2014-10-17 Clarifying specs, general updates.
    [fishbox.scad]
2014-10-17 Add camera supports, top cover, and wire opening.
    [fishbox.scad]
2014-10-17 Fix offset of camera supports for cutouts.
    [fishbox.scad]
2014-10-17 Truly solid sides, more versatile cutouts module, more cutouts on top cover.
    [fishbox.scad]
2014-10-17 More tweaks to camera enclosure including one important opening fix for flex cable holder and a bunch of silly stuff.
    [piCameraEnclosure.scad, piCameraEnclosure.stl]
2014-10-17 Another round of tweaks based on a print.
    [piCameraEnclosure.scad]
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2014-10-20 Tweaks to the camera enclosure. Now the opening is far too wide, so... ?
    [piCameraEnclosure.scad]
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2014-10-22 Fixes/improvements for heatmaps.
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2014-10-24 More room for lens protrusion, add opening for LED/resistor on front, and make more adjustable height-wise.
    [piCameraEnclosure.scad, piCameraEnclosure.stl]
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2014-11-05 RPI holder added to fishbox.
    [fishbox.scad]
2014-11-10 First shot at a simple test of cuts/kerf widths on the laser cutter.
    [cut_test.scad]
2014-11-11 Ready to test the laser cutter.
    [cut_test.scad]
2014-11-12 Fix positioning of cover (lay flat on same plane as enclosure)
    [piCameraEnclosure.scad, piCameraEnclosure.stl]
2014-12-09 Setup for projecting parts to DXF.
    [fishbox.scad]
2014-12-09 Move fishbox design to its own directory.
    [fishbox.scad]
2014-12-09 Setup for 1/4" thickness, fix two issues exposed by thicker material setting.
    [fishbox.scad]
2014-12-09 Update to real measurements.
    [fishbox.scad]
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2015-01-13 Update thickness based on measurement / cut test. Improve base.
    [fishbox.scad]
2015-01-15 Improved light bar opening to allow sliding out of the way.
    [fishbox.scad]
2015-01-21 Fixes and improvements to hanging supports.
    [fishbox.scad]
2015-01-21 Many improvements, primarily around the hanging supports.
    [fishbox.scad]
2015-01-21 Thickness update for new material.
    [fishbox.scad]
2015-01-21 Fixes, bug workaround.
    [fishbox.scad]
2015-01-23 Slightly wider/longer, simpler 'opening' for connector, LED, etc.
    [piCameraEnclosure.scad, piCameraEnclosure.stl]
2015-01-27 Altered measurements for hardboard, tweaked height and lightbar position, rounded/truncated overhangs on vertical faces.
    [fishbox.scad]
2015-01-27 Tweak measurements to better fit tank.
    [fishbox.scad]
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2015-01-31 Allow different thickness for window panel.
    [fishbox.scad]
2015-02-02 Parameter cleanup to match modified module signature.
    [fishbox.scad]
2015-02-02 Simpler cut test, for use on hardboard.
    [cut_test2.scad]
2015-02-02 Tweak measurement after hardboard cut test.
    [fishbox.scad]
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2015-02-05 Move wire opening, fix bug in cutouts on vert face.
    [fishbox.scad]
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2015-02-16 Fix divide-by-zero in TSL2561.
    [TSL2561.py]
2015-02-16 Fix bogus initial sensor reading.
    [sensors.py]
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2015-03-06 Tweaks based on latest cut.
    [fishbox.scad]
2015-03-19 Fixing hanging supports; other minor tweaks.
    [fishbox.scad]
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2015-03-19 STL output of new OpenSCAD version.
    [piCameraEnclosure.stl]
2015-03-20 Fix error introduced by rounded hanging supports.
    [fishbox.scad]
2015-03-20 Fix for new camera enclosure size.
    [fishbox.scad]
2015-03-20 Fix bug in rounded hanging supports.
    [fishbox.scad]
2015-03-20 Centralize , fix window_thickness issue w/ sides.
    [fishbox.scad]
2015-03-30 Remove old, uneeded design file.
    [fishybox.skp]
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2015-06-09 Slightly better error checking.
    [experiment.py, tracking.py]
2015-06-11 Fix lightbar stimulus conditions/updates.
    [stimulus.py]
2015-06-12 Fixes to lightbar stim (needs more work).
    [experiment.py, stimulus.py]
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2015-06-12 Correct max PWM value.
    [stimulus.py]
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2015-06-12 Initial commit of circuit layout. No sensors yet.
    [fishbox_circuit.fzz]
2015-06-16 Fix lightbar flashing stimulus.
    [stimulus.py]
2015-06-16 Allow assigning different materials to the window.
    [fishbox.scad]
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2015-06-29 Avoid wiringpi's crash out if not run as sudo (breaks camera interface until reboot).
    [stimulus.py]
2015-07-23 Improve handling of missing wiringpi2.
    [stimulus.py]
2015-07-23 Remove --notrack option (also fixed indentation issue from editing on rpi).
    [experiment.py]
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2015-07-29 Improved multi-process interactions.
    pipe.recv() could return None when the connection is broken, so I needed
    to differentiate that from sending None myself. Now, I no longer send None
    as a stimulus value.
    Also updated use of pipes to better match suggestions in multiprocessing doc
    programming guidelines.
    [controllers.py, experiment.py, stimulus.py]
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2015-07-31 Fix crash when parsing empty/incomplete track line.
2015-09-09 Fix bug w/ --time-from-trigger crashing.
    [experiment.py]
2015-10-09 New varthreshold to reduce noise a bit.
    [tracking.py]
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2015-10-20 Fix -w issue under Cygwin; general cleanup and refactoring.
    [experiment.py, tracking.py]
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2015-10-26 Improve/correct setting exposure in Stream.
    [tracking.py]
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2015-11-06 Remove light bar; add mask panel.
    [fishbox.scad]
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2015-11-06 Add tank support parts.
    [fishbox.scad]
2015-11-10 Oops. Put the mask panel on the correct side of the tank.
    [fishbox.scad]
2015-11-10 Shift wire opening to be less in the camera's way, more towards where wires are used inside anyway.
    [fishbox.scad]
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2015-11-10 Mask opening tweak again.
    [fishbox.scad]
2015-11-11 Fix mask panel tabs to be symmetric (won't matter which way bottom is installed).
    [fishbox.scad]
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2015-12-11 Add mounting holes for mounting camera w/ posts.
    [fishbox.scad]
2015-12-11 Commit to post-mounted camera; update design for stacking.
    [fishbox.scad]
2015-12-14 Fix placement of top cover cut for mask.
    [fishbox.scad]
2015-12-15 Tweak for fishtank section cover; new paneling plan.
    [fishbox.scad]
2015-12-15 Shrunk entire box down 1cm in height (better fit for paneling).
    [fishbox.scad]
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2016-01-10 Fix sync UI (only enable button when actually done; fix spurious alert on leaving page)
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2016-01-16 Fix lightbar stimulus to turn off at program end; minor cleanup, too.
    [stimulus.py]
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2016-01-29 Fix for image-capture making camera unusable for tracking.
2016-02-11 Better tracking. Only 'allow' brightness tracking for small movement.
    The idea is that the background subtractor will (should) only fail when
    the fish is barely moving or motionless, so the fallback of using the
    brightness tracker should only consider and return bright objects near
    the fish's last-estimated position. This should not change over time,
    as the background subtractor should pick up on any movement that could
    get the fish somewher else.
    [experiment.py, tracking.py]
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2016-02-12 Fix for loggin, tweak for distance filtering.
    [experiment.py, tracking.py]
2016-02-26 Tweak hardboard thickness/tolerance; tweak mask opening/design; add finger hole to tank support acrylic.
    [fishbox.scad]
2016-03-01 Update tank baffle design w/ real measurements.
    [tank_baffle.dxf]
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2016-03-07 AWB fix, I think.
    [tracking.py]
2016-03-15 Split top into two parts in DXF.
    [fishbox.scad]
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2016-05-26 Fixed/improved saftey limit, electrical stimulus config.
    [fishbox_circuit.fzz]
2016-06-15 New lid and baffle design for electric shock experiments.
    [tank_baffle_for_shock.dxf, tank_lid_for_shock.dxf]
2016-06-15 Tweaks for fit and added cutouts for new wires.
    [fishbox.scad]
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2017-06-09 Fixes and refactoring for heatmap code.
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2017-06-21 Fix heatmaps, fix positioning of debugframe markers.
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2017-06-21 Fix path to debug frames.
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2017-06-29 Fix for crashing on analysis w/ 1 sample beyond minute boundary.
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2017-07-01 Fix issues w/ processing older track files.
2017-07-16 Fix Python3 mjpeg streaming issue; fix Chrome mjpeg issue (drop dud frames).
2017-07-18 Fix logic/state for saving debug frames on status changing from acquired.
    [experiment.py]
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2017-07-20 Fix (probably) the issue w/ relative_url filter when served via Github pages.
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2017-07-26 Fix min/max input sizes in filters.
2017-07-26 Fix for debug frames off bottom of window.
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2017-07-29 Minor fixes; filters handle bools correctly.
2017-08-01 Further fixes for pathlib switch.
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2017-09-16 Reorganize design files; add dist/ folder with pre-built DXFs.
    [bottom.dxf, end1.dxf, end2.dxf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]
2017-09-19 Fix bug in stimulus freq_Hz handling.
    [stimulus.py]
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2017-11-13 Add alternating electrical stimulus (to circuit and code).
    [box_circuit.fzz]
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2017-12-10 Switch to inpsect.signature() to avoid deprecation notice.
2018-01-23 Fix bug in debug frame indicators (missing past first chunk of trace plot).
2018-01-29 Correct tank lid DXF.
    [tank_lid_for_shock.dxf]
2018-02-05 Fix zombie process confusing PID detection.
2018-02-05 Fixes and improvements for robust threads.
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2020-01-28 Fix issue with browser refusing to submit forms without values in length fields (and producing no helpful feedback about that, in Firefox's case).
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
